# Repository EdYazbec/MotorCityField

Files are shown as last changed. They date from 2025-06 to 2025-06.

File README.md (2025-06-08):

# MotorCityField

This repository contains the source files for the Motor City Field, a full-sized FRC practice field constructed from commonly available building materials.

This field design is based on the AndyMark 2008 Wooden Field, with modifications for ease of assembly and repeated tear-down and setup.

The goal of this design is to create an adaptable, easy-to-manufacture, and reasonably close-to-life field for use by FRC teams.

The Motor City Field was designed, built, and run by the Motor City Alliance, led by FRC Team 5577, The Kinematic Wolves.

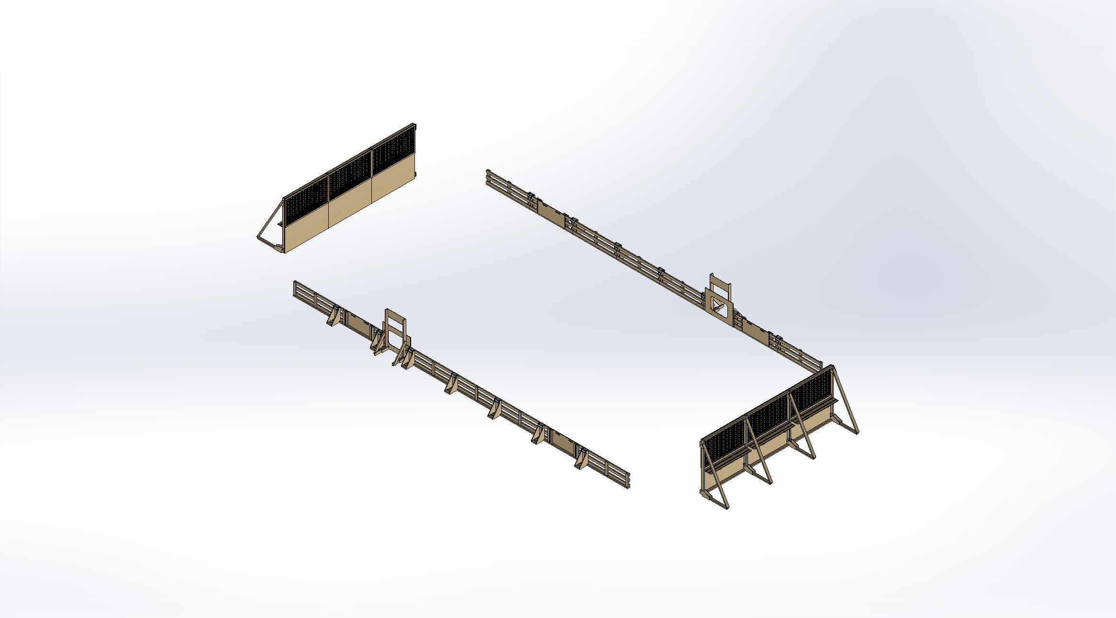
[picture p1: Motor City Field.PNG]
Motor City Field


## Limitations

Because the official FRC field changes every year, only the evergreen field elements are included in this design. These elements must be adapted with season-specific team field elements to produce a representative field for the current game.

This field is not fully enclosed by default, although it could be adapted to do so. It is intended to be combined with the season-specific team field elements to create a full, enclosed, representative field.

## Safety

FRC robots can be dangerous, especially in a testing environment. This field is designed to be robust; however, a modern FRC robot at full speed and power may exceed the safety provisions of this field.

It is the responsibility of those implementing this design to establish appropriate safety protocols to ensure the safe operation of robots on this field.

## Perimeter

The perimeter segments are designed to match the length of the standard segments used in the evergreen portion of the official field. This allows for easy reconfiguration each season and simpler integration with the season-specific team elements.

## Driver Stations

The driver station walls are designed to match the dimensions of the official field as closely as possible. These walls require additional bracing compared to the perimeter walls. Typically, the season-specific field has additional elements that connect to or insert into the driver station walls. It is up to the end user to finalize the details for each season.

## Drawing Package

The included drawing package contains engineering drawings for the evergreen portion of the Motor City Field, as well as integration with some 2025 team field elements. This package may be updated in the future.  

## Notes

- This repository focuses on the evergreen field elements; users will need to adapt or add season-specific elements each year.  
- Please refer to the LICENSE and any Third-Party Notices for licensing information.

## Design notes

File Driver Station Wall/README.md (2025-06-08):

# Driver Station Wall

The Driver Station wall is a 8' wall separating the robot drivers from the robots on the field.  
The wall is created from Driver Stations, Driver Station Braces, and any season specific field elements integrated into the wall.  
The goal is to prevent this.  
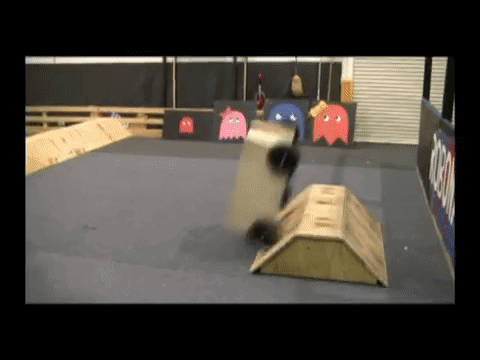
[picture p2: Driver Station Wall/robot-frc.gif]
Rouge Robot
.  

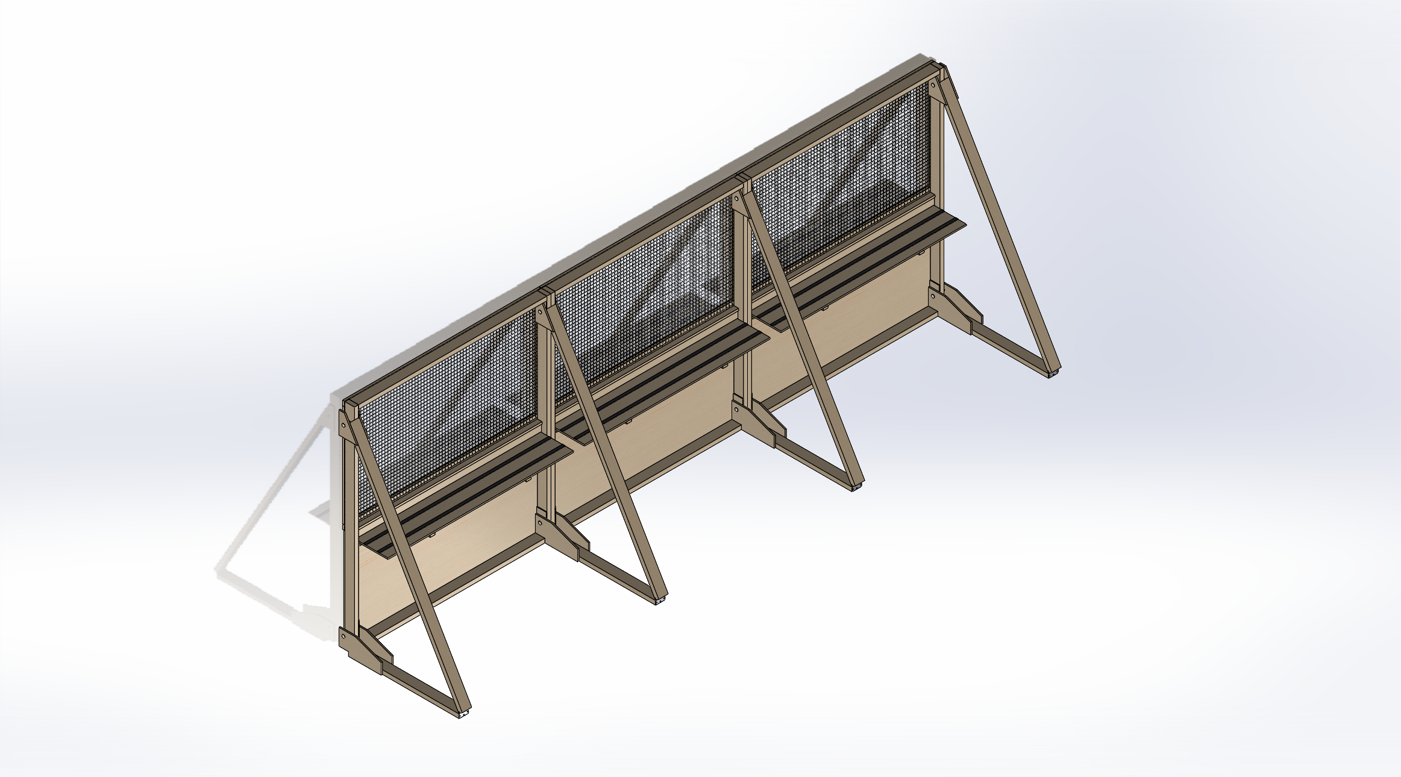
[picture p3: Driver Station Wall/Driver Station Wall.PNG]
Driver Station Wall


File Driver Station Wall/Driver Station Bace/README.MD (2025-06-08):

# Wall Brace

The Wall Brace provide structural re-enforcement between sections of the driver station wall.  
These also allow the Driver Station Walls to stand upright.  
The Wall Braces have a hing, allowing them to store easily.
It is recommended to place sand bags or similar ballast on the braces at the ground to provide additional stability.  

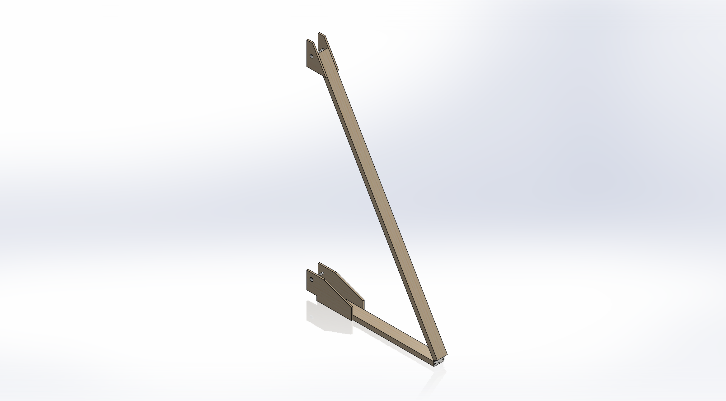
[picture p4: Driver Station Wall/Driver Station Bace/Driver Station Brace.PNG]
Driver Station Brace


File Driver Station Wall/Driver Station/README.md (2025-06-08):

# Driver Station

The Driver Station is a 8' wall segment separating the robot drivers from the robots on the field.  
The Driver Station provides a foldable shelf for the operator consol.
It is constructed from 2x4 and 1x2 lumber, as well as plywood of varying thickness.  
The steel mesh is a safety item, providing visibility for the robot operators, while protecting them from robots that may hit the wall, or from errant game pieces.  

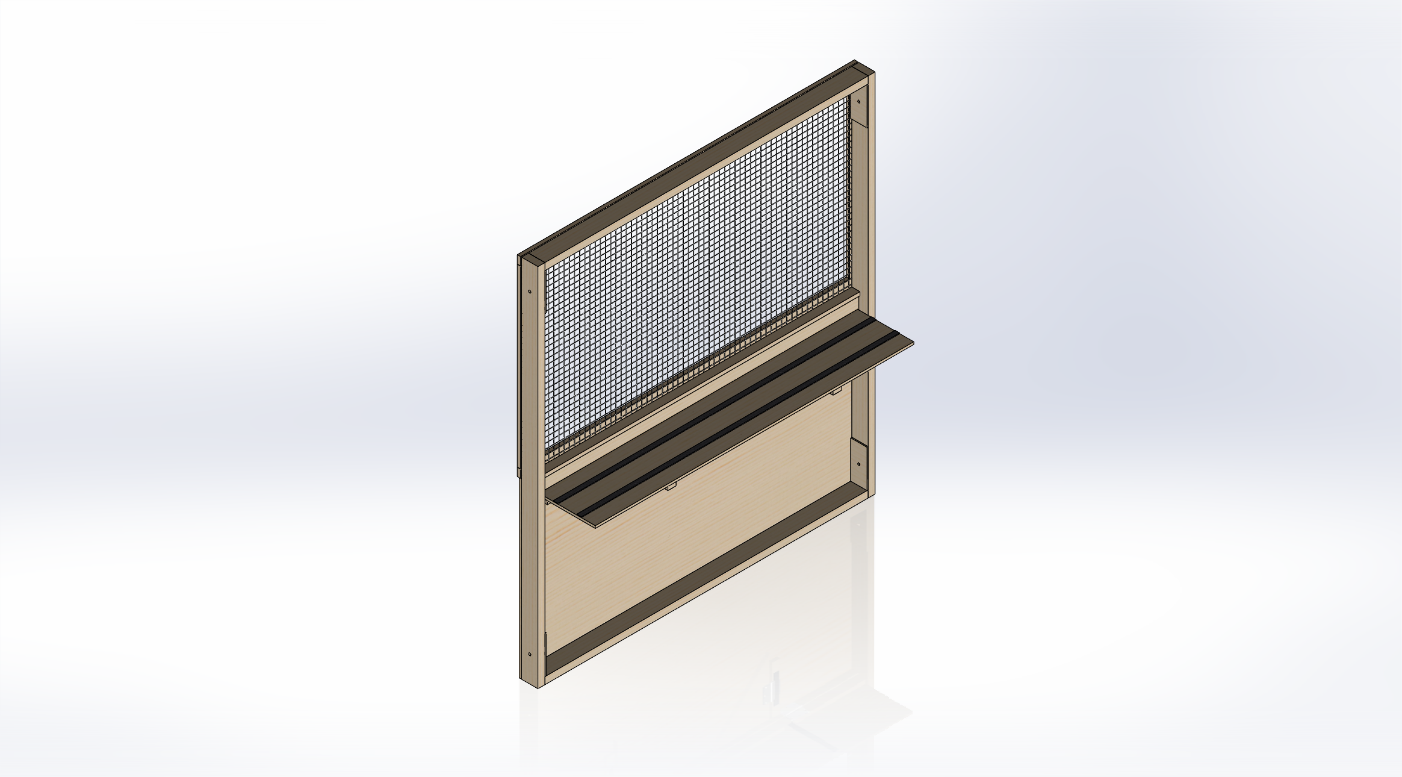
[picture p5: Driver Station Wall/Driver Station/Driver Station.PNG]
Driver Station


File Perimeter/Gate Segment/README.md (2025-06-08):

# Gate Segment

The Gate Segment is meant to provide access to the field without stepping over the perimeter wall.  
It is constructed from 2x4 and 1x2 lumber, aluminum U channel, and 3/4" plywood.  
3" screws recommended for assembly of the 2x4's.

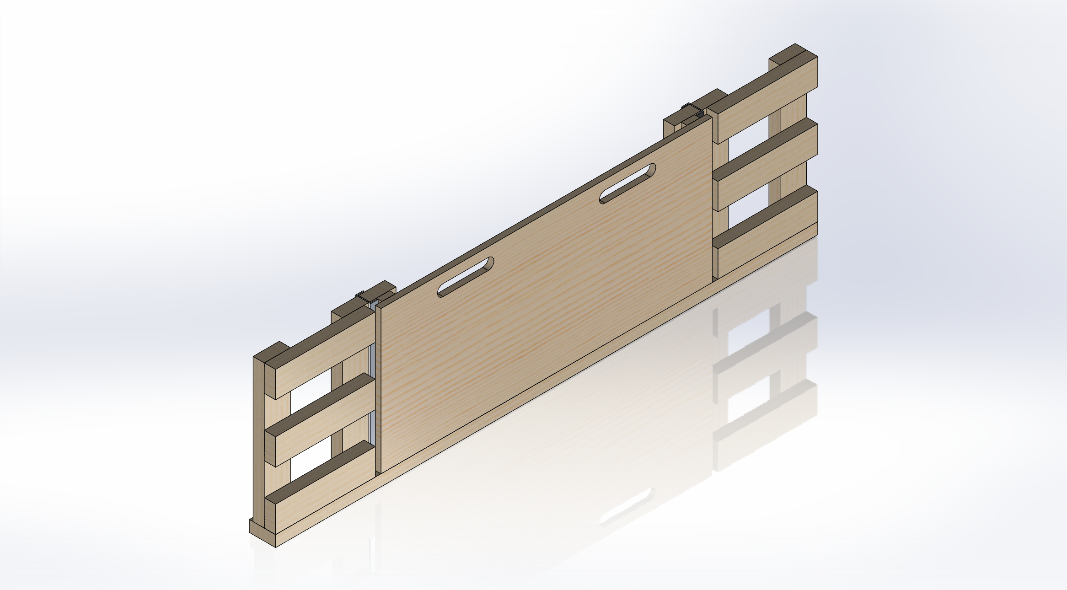
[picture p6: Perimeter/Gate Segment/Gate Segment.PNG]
Gate Segment


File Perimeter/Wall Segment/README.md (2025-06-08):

# Wall Segment

The Wall Segment forms the majority of the field perimeter wall.  
It is constructed from 4 2x4's.  
3" screws recommended for assembly of the 2x4's.  

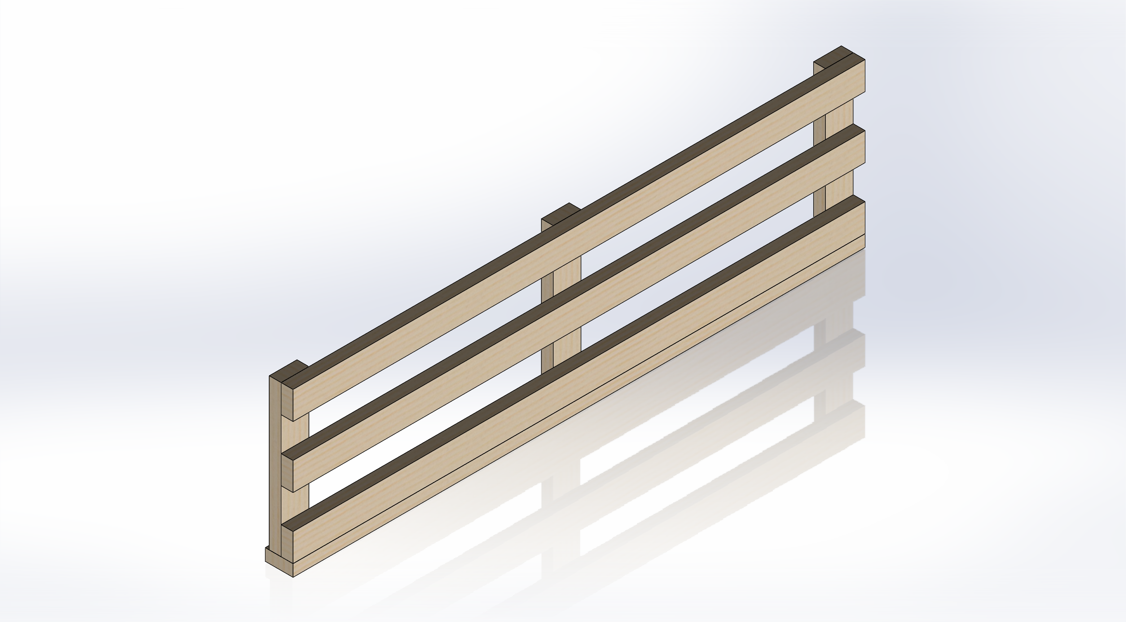
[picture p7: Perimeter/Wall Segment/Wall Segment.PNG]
Wall Segment


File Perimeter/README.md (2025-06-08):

# Perimeter

The Perimeter is a 20" tall wall that encloses the field.  
The purpose of the perimeter is to provide a clear boundary for the field, safely separating robots and humans.  
The Perimeter is constructed from Wall Segments, Gate Segments, Perimeter Braces, Field clips, and any additional season specific field elements.  

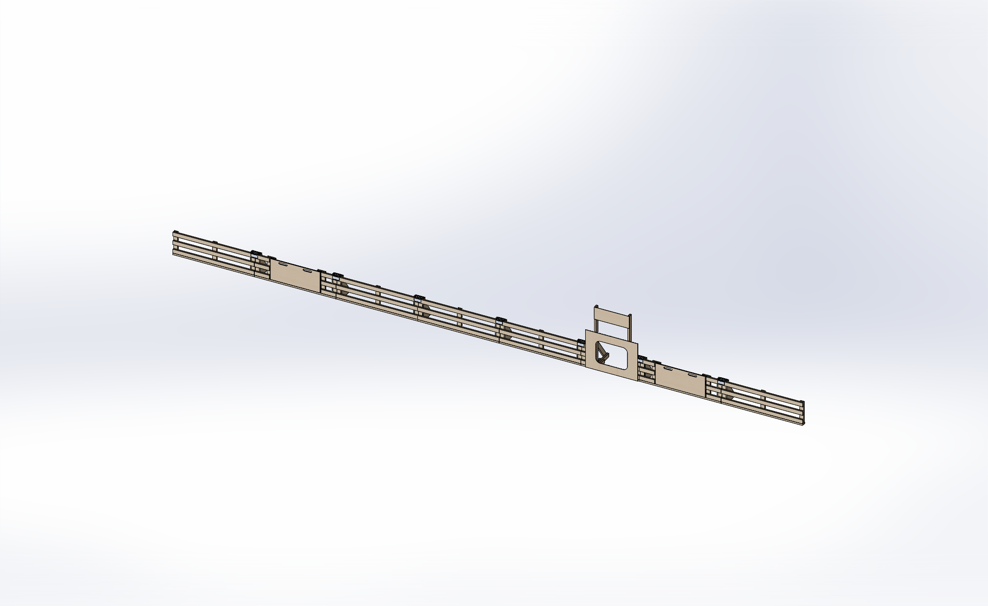
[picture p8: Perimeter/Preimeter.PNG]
Perimeter


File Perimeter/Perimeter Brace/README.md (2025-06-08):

# Perimeter Brace

The Perimeter Brace adds additional rigidity to the Perimeter wall where two Wall Segments or a Wall Segment and a Gate Segment meet.  
The Perimeter Brace is constructed from 2x4 lumber, and 3/4" plywood.  
The 2x4 lengths can be sourced from off cuts of other 2x4's from this build.  

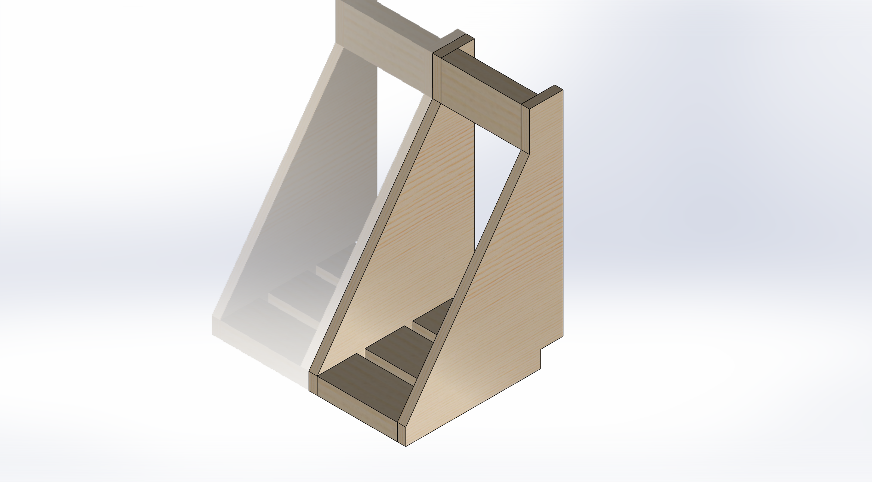
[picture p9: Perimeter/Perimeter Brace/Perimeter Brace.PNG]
Perimeter Brace


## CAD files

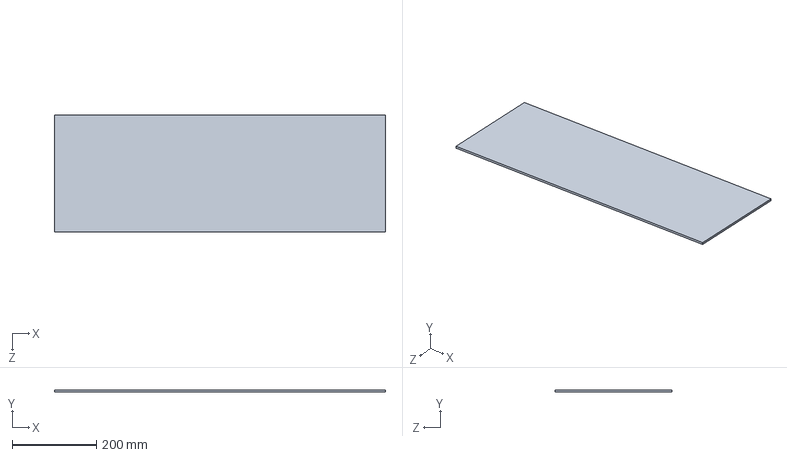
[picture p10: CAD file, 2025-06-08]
2025 Specific/TE-25100/TE-25106.SLDPRT
787.4 x 5.56 x 279.4 mm

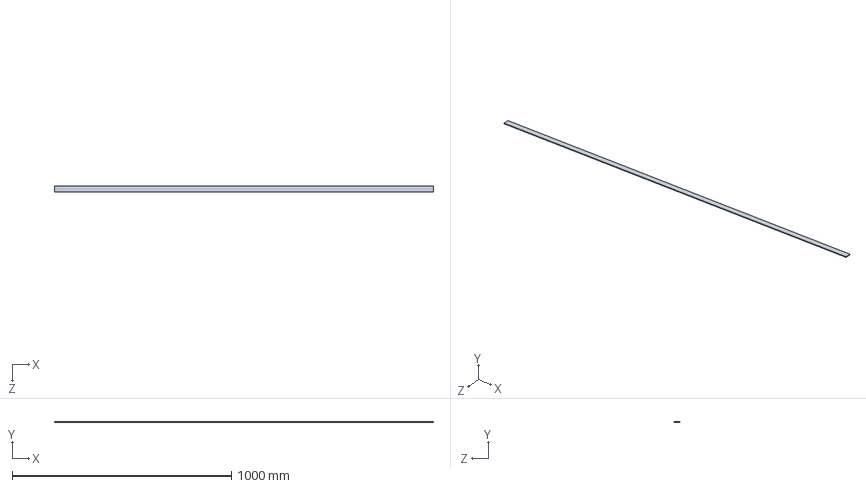
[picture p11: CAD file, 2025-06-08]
Common/1in Hook Tape.SLDPRT
1727.2 x 3.17 x 25.4 mm

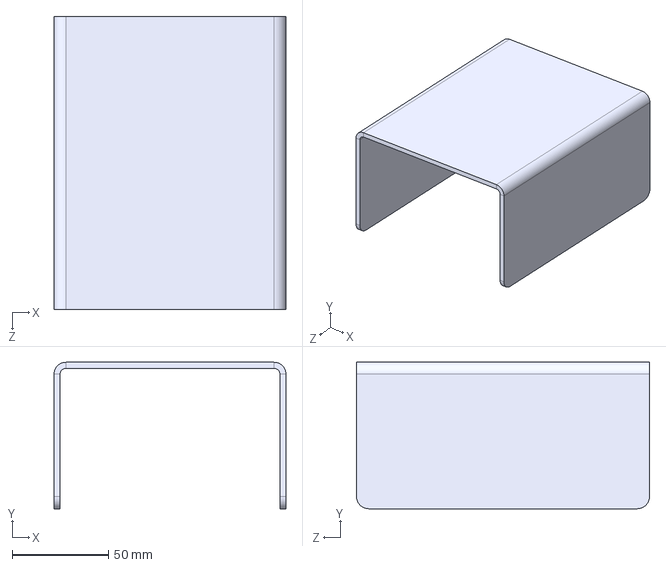
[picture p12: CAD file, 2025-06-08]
Drawing Package/Perimeter/Field Clip.STEP
120.7 x 76.2 x 152.4 mm

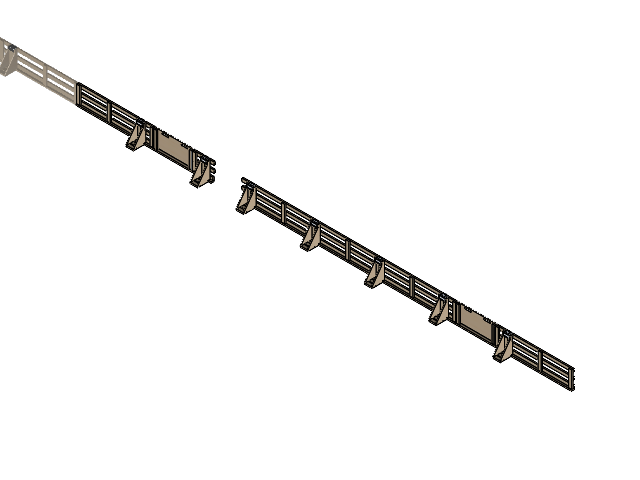
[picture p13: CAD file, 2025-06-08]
2025 Specific/Preimeter.SLDASM
2x4 x 99
Gate Door Pannel x 2
1x2 x 4
2in Hook Tape x 30
u channel x 4
TE-25101
TE-25102 x 2
TE-25103 x 2
TE-25105 x 4
TE-25106
TE-25104 x 2
Wall gusset x 14
Field Clip x 7

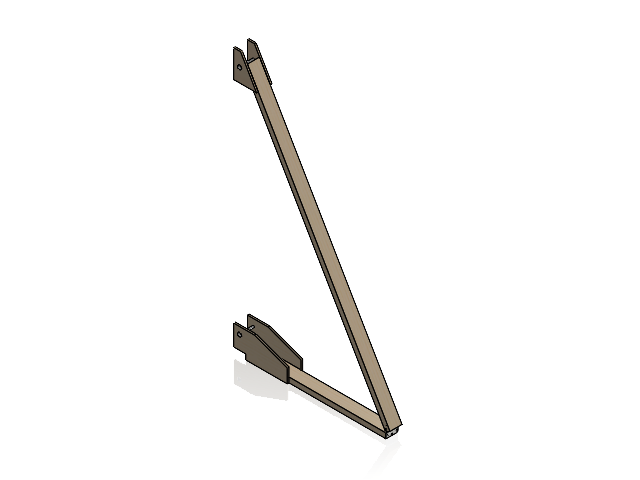
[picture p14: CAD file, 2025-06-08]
Driver Station Wall/Driver Station Bace/Driver Station Brace.SLDASM
2x4
2x4 DS angled piece
2in Hook Tape
DS Brace Bottom Fin x 2
DS Brace Top Fin x 2
92356A158 x 2
1513A51_Mortise-Mount Hinge with Holes
92141A033 x 2
92146A033 x 2
91845A310 x 2

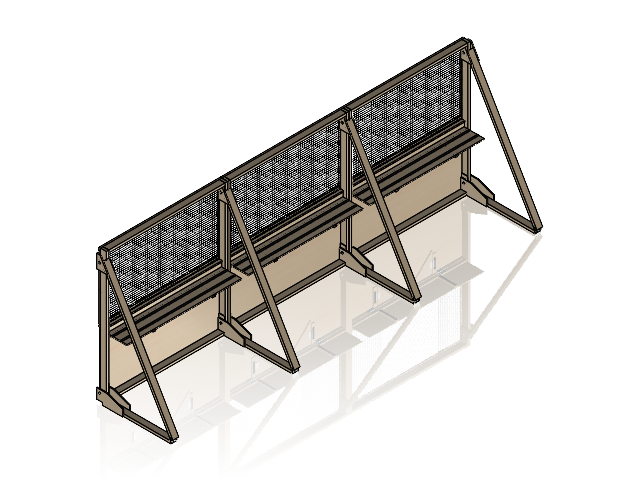
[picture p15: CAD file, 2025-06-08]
Driver Station Wall/Driver Station Wall.SLDASM
2x4 x 19
DS Wall Plate x 3
47065T295 x 3
1x2 x 30
DS Shelf Slab x 3
1513A51_Mortise-Mount Hinge with Holes x 16
1in Hook Tape x 12
DS Shelf Support x 6
0.5in Loop Tape x 6
1in Loop Tape x 6
2in Hook Tape x 7
DS Spacer x 12
2x4 DS angled piece x 4
DS Brace Bottom Fin x 8
DS Brace Top Fin x 8
92356A158 x 8
92141A033 x 8
92146A033 x 8
91845A310 x 8

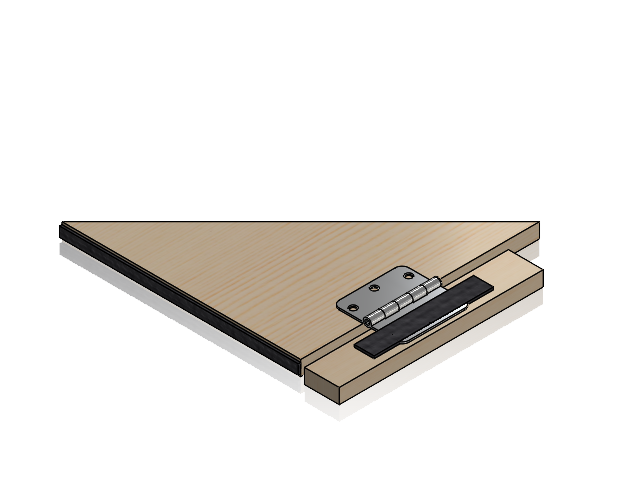
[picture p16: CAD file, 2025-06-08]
Driver Station Wall/Driver Station/DS Shelf Support LH.SLDASM
1x2
DS Shelf Support
1513A51_Mortise-Mount Hinge with Holes
0.5in Loop Tape
1in Loop Tape

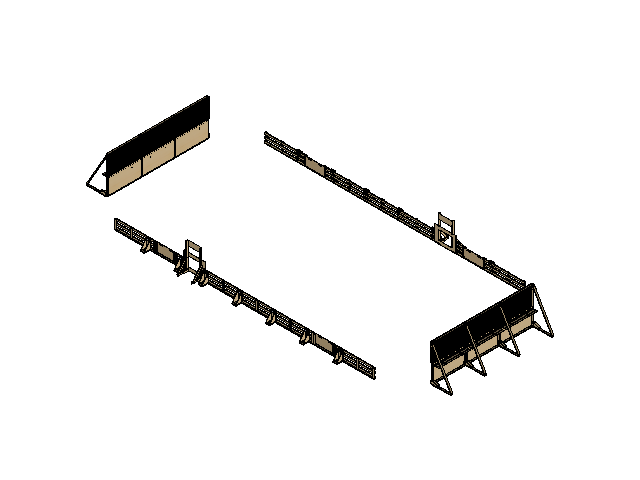
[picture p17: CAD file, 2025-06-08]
Motor City Field.SLDASM
2x4 x 236
DS Wall Plate x 6
47065T295 x 6
1x2 x 68
DS Shelf Slab x 6
1513A51_Mortise-Mount Hinge with Holes x 32
1in Hook Tape x 24
DS Shelf Support x 12
0.5in Loop Tape x 12
1in Loop Tape x 12
2in Hook Tape x 74
DS Spacer x 24
2x4 DS angled piece x 8
DS Brace Bottom Fin x 16
DS Brace Top Fin x 16
92356A158 x 16
92141A033 x 16
92146A033 x 16
91845A310 x 16
Gate Door Pannel x 4
u channel x 8
TE-25101 x 2
TE-25102 x 4
TE-25103 x 4
TE-25105 x 8
TE-25106 x 2
TE-25104 x 4
Wall gusset x 28
Field Clip x 14

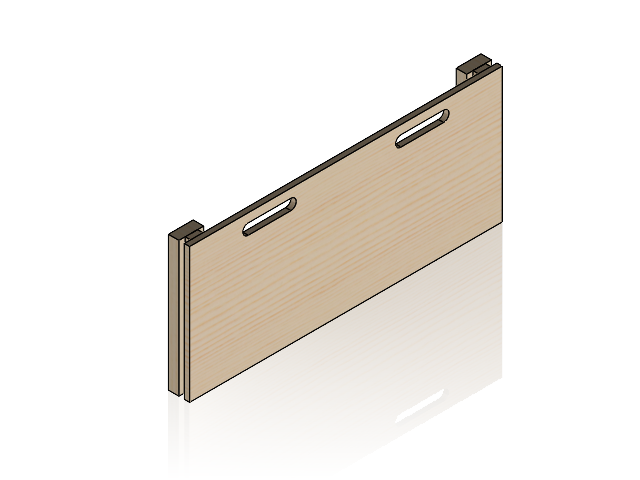
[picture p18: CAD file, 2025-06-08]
Perimeter/Gate Segment/Gate Door.SLDASM
Gate Door Pannel
2x4 x 2
1x2 x 2

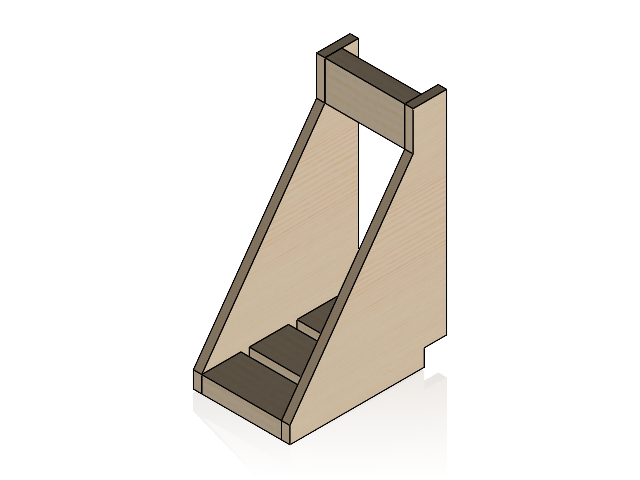
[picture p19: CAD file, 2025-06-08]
Perimeter/Perimeter Brace/Perimeter Brace.SLDASM
2x4 x 4
Wall gusset x 2
2in Hook Tape x 3

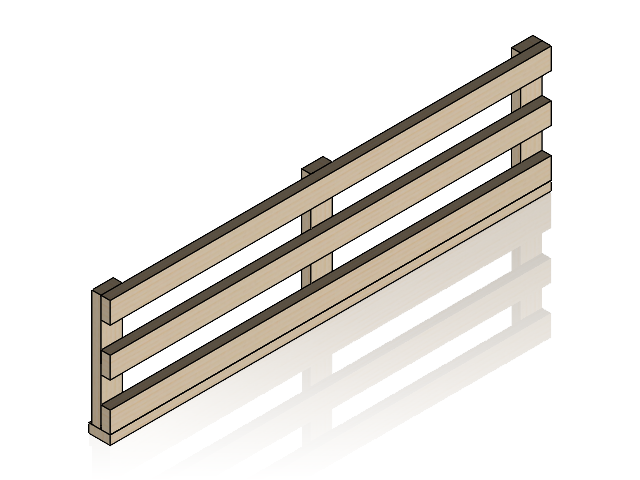
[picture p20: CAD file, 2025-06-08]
Perimeter/Wall Segment/Wall Segment.SLDASM
2x4 x 7
2in Hook Tape

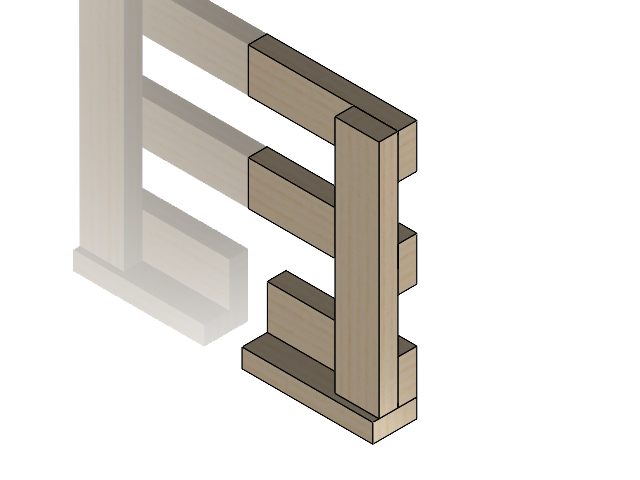
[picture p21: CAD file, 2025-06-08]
2025 Specific/Processor Padding B.SLDASM
2x4 x 5
2in Hook Tape

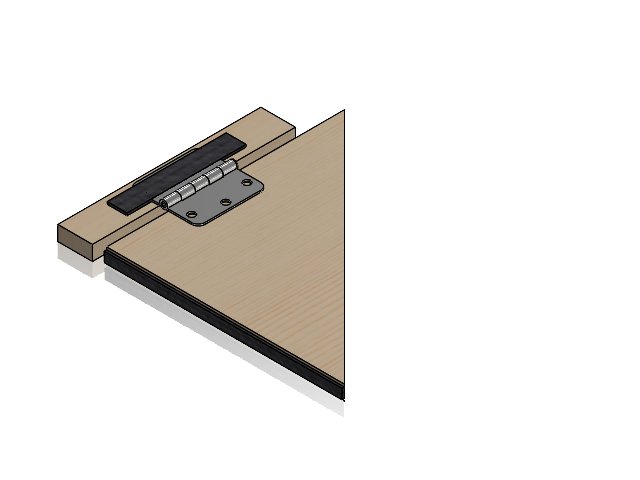
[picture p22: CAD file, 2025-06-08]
Driver Station Wall/Driver Station/DS Shelf Support RH.SLDASM
1x2
DS Shelf Support
1513A51_Mortise-Mount Hinge with Holes
0.5in Loop Tape
1in Loop Tape

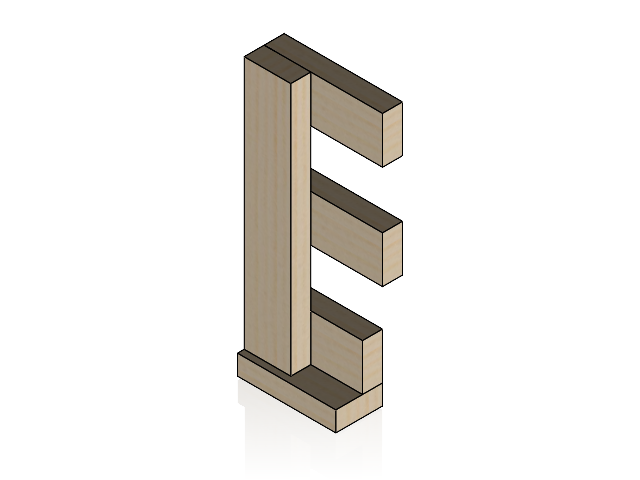
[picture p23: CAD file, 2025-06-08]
2025 Specific/Processor Padding A.SLDASM
2x4 x 5
2in Hook Tape

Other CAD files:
2025 Specific/TE-25100/TE-25100.SLDASM
Perimeter/Gate Segment/Gate Segment.SLDASM
Driver Station Wall/Driver Station/Driver Station.SLDASM
Driver Station Wall/Driver Station/DS Shelf.SLDASM
2025 Specific/Preimeter.SLDDRW
2025 Specific/Processor Padding A.SLDDRW
2025 Specific/Processor Padding B.SLDDRW
2025 Specific/TE-25100/TE-25101.SLDPRT
2025 Specific/TE-25100/TE-25102.SLDPRT
2025 Specific/TE-25100/TE-25103.SLDPRT
2025 Specific/TE-25100/TE-25104.SLDPRT
2025 Specific/TE-25100/TE-25105.SLDPRT
Common/0.5in Loop Tape.SLDPRT
Common/1in Loop Tape.SLDPRT
Common/1x2.SLDPRT
Common/2in Hook Tape.SLDPRT
Common/2x4.SLDPRT
Driver Station Wall/Driver Station Bace/2x4 DS angled piece.SLDDRW
Driver Station Wall/Driver Station Bace/2x4 DS angled piece.SLDPRT
Driver Station Wall/Driver Station Bace/DS Brace Bottom Fin.SLDDRW
Driver Station Wall/Driver Station Bace/DS Brace Bottom Fin.SLDPRT
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

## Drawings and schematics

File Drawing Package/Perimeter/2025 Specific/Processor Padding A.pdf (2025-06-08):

ITEM NO. | PART NUMBER | MATERIAL | QTY.
1 | 7.375" | 2X4 | 2

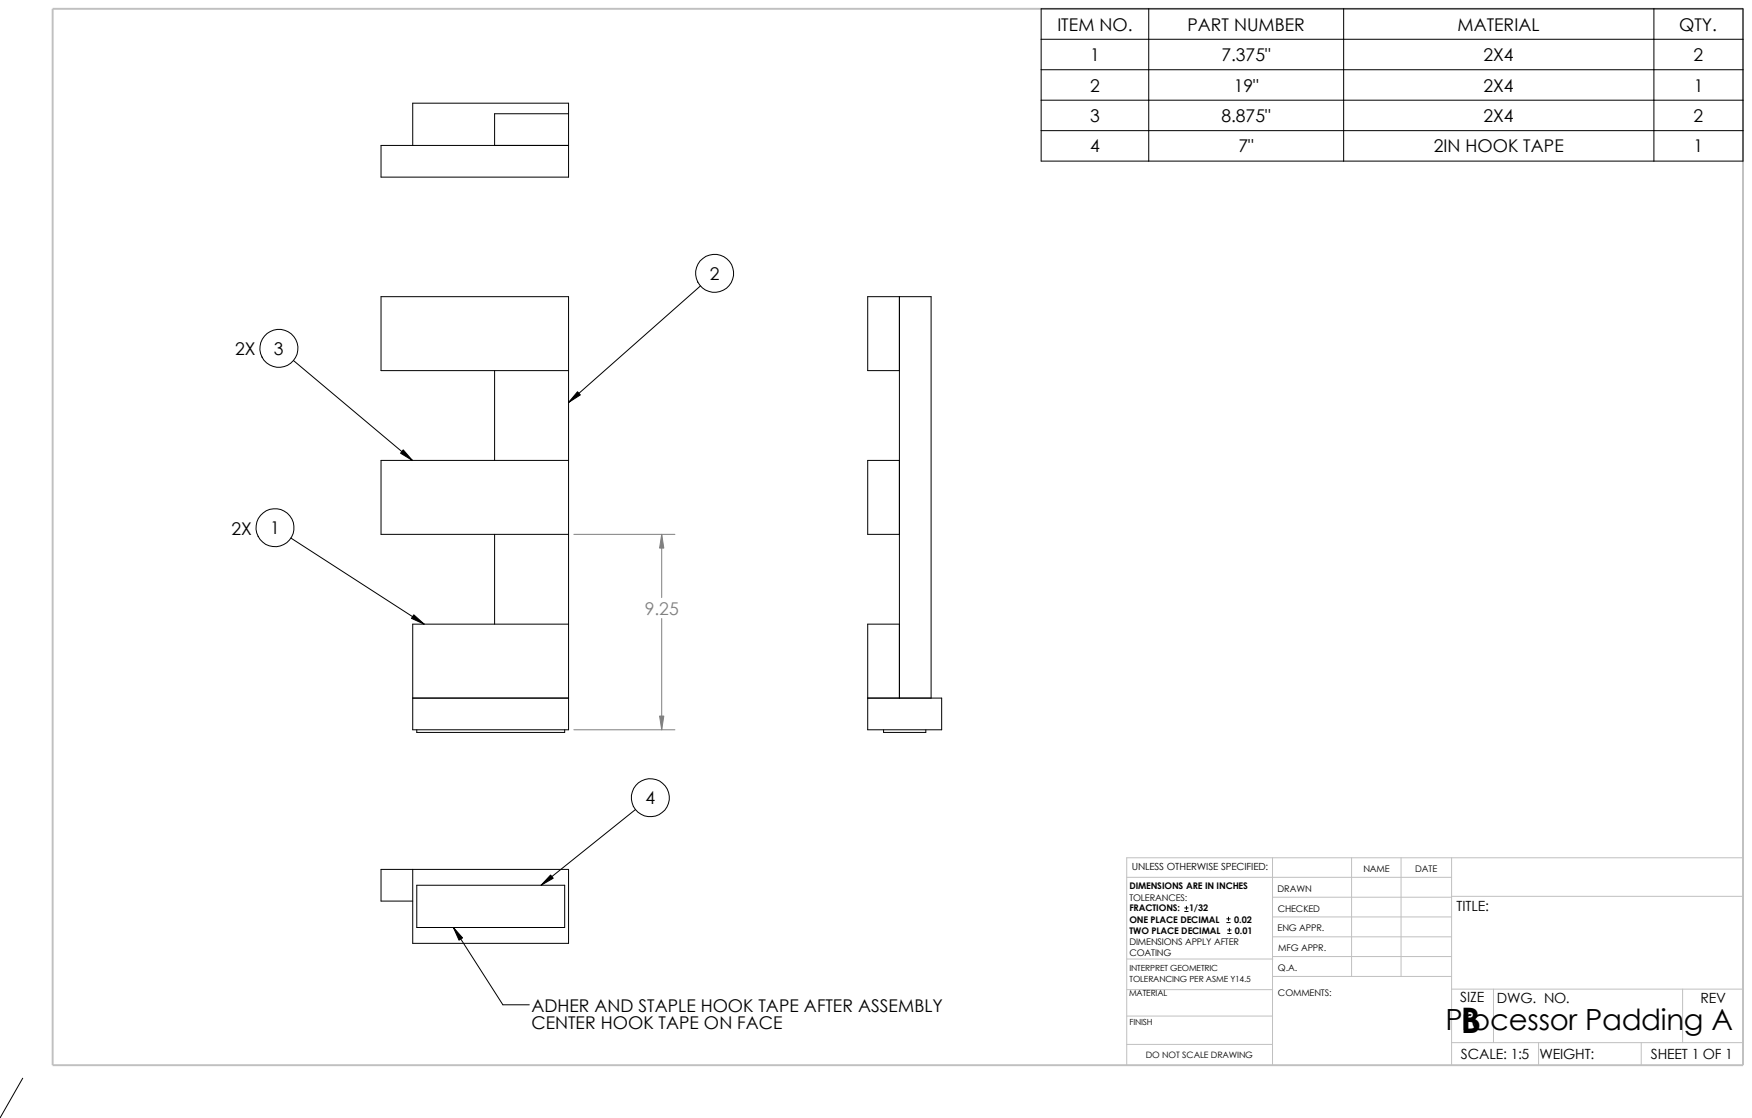
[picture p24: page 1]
SCALE: 1:5; DO NOT SCALE DRAWING; WEIGHT:; REV Processor Padding A B; SIZE; COMMENTS:; DWG. NO.; SHEET 1 OF 1; FINISH; MATERIAL

2 | 19" | 2X4 | 1
3 | 8.875" | 2X4 | 2
4 | 7" | 2IN HOOK TAPE | 1

UNLESS OTHERWISE SPECIFIED: | | NAME | DATE
DIMENSIONS ARE IN INCHES TOLERANCES: FRACTIONS: 1/32 ONE PLACE DECIMAL 0.02 TWO PLACE DECIMAL 0.01 DIMENSIONS APPLY AFTER COATING | DRAWN

CHECKED | | | TITLE:

ENG APPR.
MFG APPR.

INTERPRET GEOMETRIC TOLERANCING PER ASME Y14.5 | Q.A.

ADHER AND STAPLE HOOK TAPE AFTER ASSEMBLY
CENTER HOOK TAPE ON FACE

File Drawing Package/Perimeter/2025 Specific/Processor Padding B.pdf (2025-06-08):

3
2X

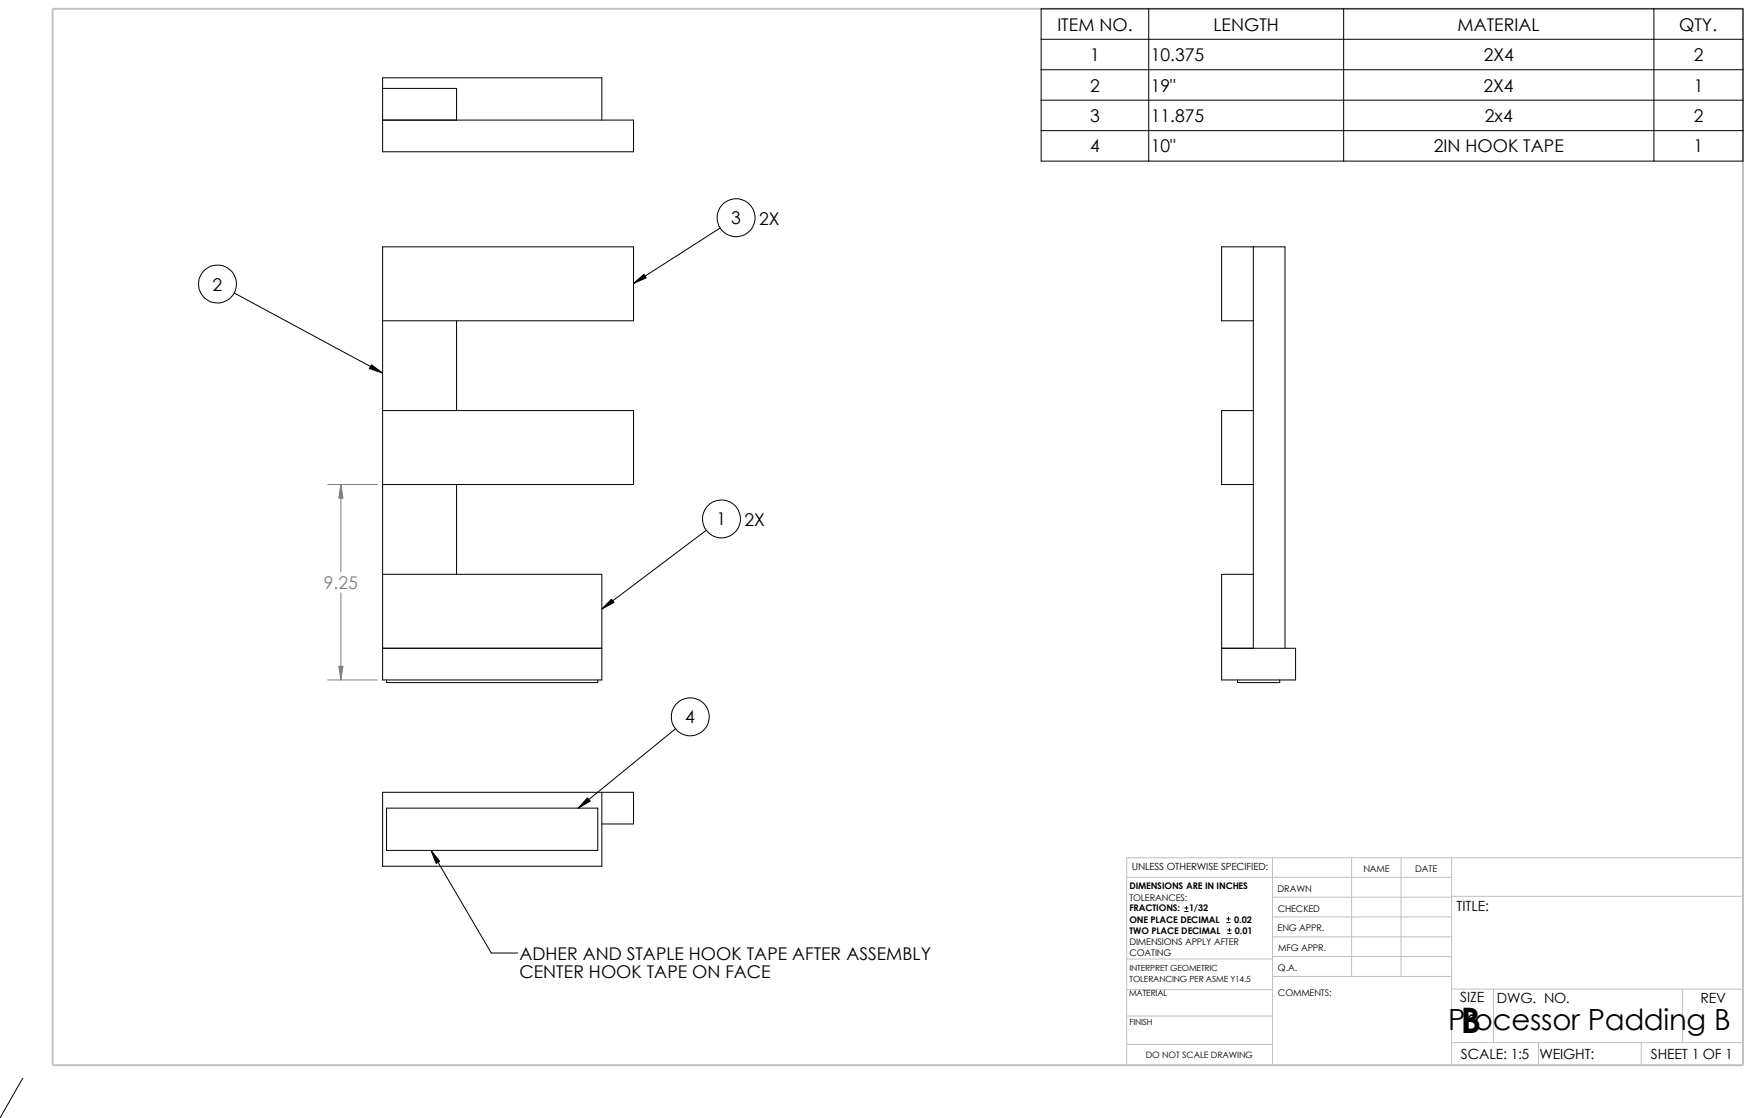
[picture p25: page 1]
SCALE: 1:5; WEIGHT:; DWG. NO.; REV; SIZE; COMMENTS:; Processor Padding B; SHEET 1 OF 1; FINISH; MATERIAL

ITEM NO. | LENGTH | MATERIAL | QTY.
1 | 10.375 | 2X4 | 2
2 | 19" | 2X4 | 1
3 | 11.875 | 2x4 | 2
4 | 10" | 2IN HOOK TAPE | 1

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

CHECKED | | | TITLE:

ENG APPR.
MFG APPR.

ADHER AND STAPLE HOOK TAPE AFTER ASSEMBLY
CENTER HOOK TAPE ON FACE

INTERPRET GEOMETRIC TOLERANCING PER ASME Y14.5 | Q.A.

DO NOT SCALE DRAWING

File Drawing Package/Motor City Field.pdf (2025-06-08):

ITEM NO. | PART NUMBER | QTY.
1 | DRIVER STATION WALL | 2

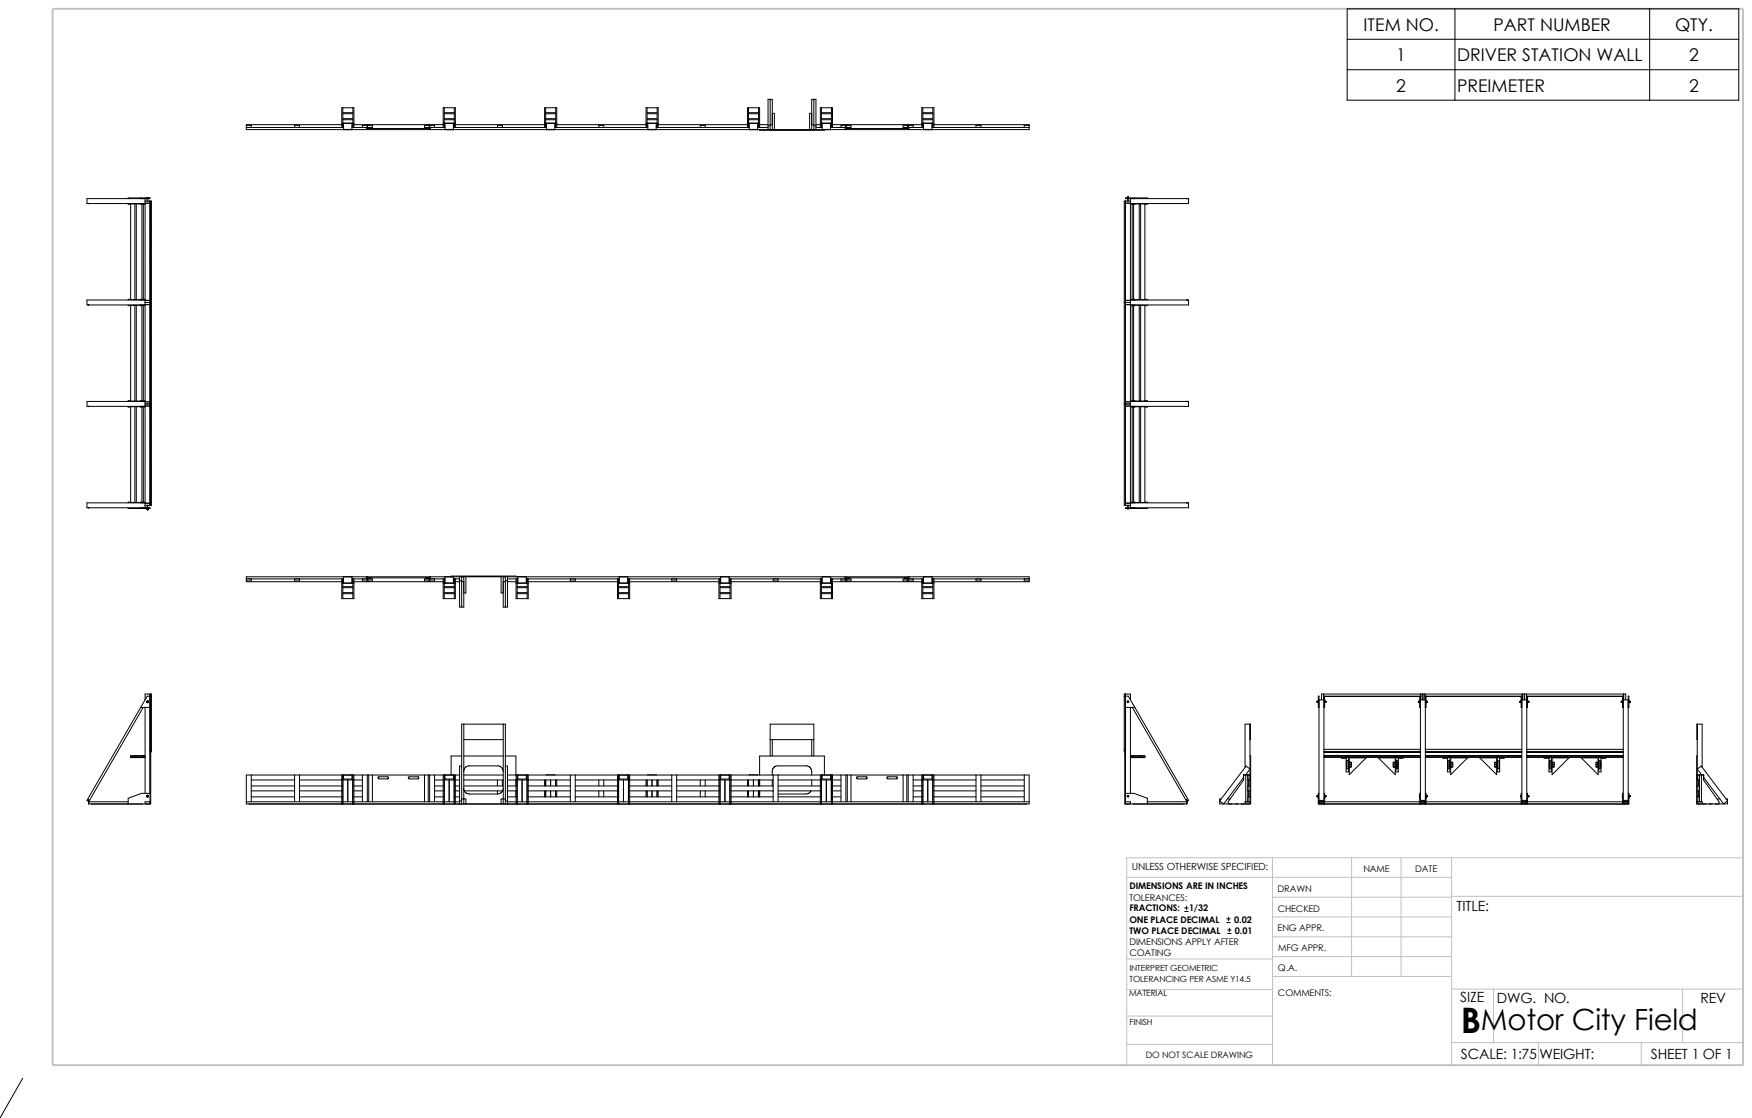
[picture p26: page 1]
COMMENTS:; DWG. NO.; REV; SCALE: 1:75 WEIGHT:; SIZE; FINISH; BMotor City Field; MATERIAL; SHEET 1 OF 1; PREIMETER

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

CHECKED | | | TITLE:

ENG APPR.
MFG APPR.

INTERPRET GEOMETRIC TOLERANCING PER ASME Y14.5 | Q.A.

DO NOT SCALE DRAWING

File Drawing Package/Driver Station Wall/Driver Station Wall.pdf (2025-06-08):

2 4X

ITEM NO. | PART NUMBER | QTY.

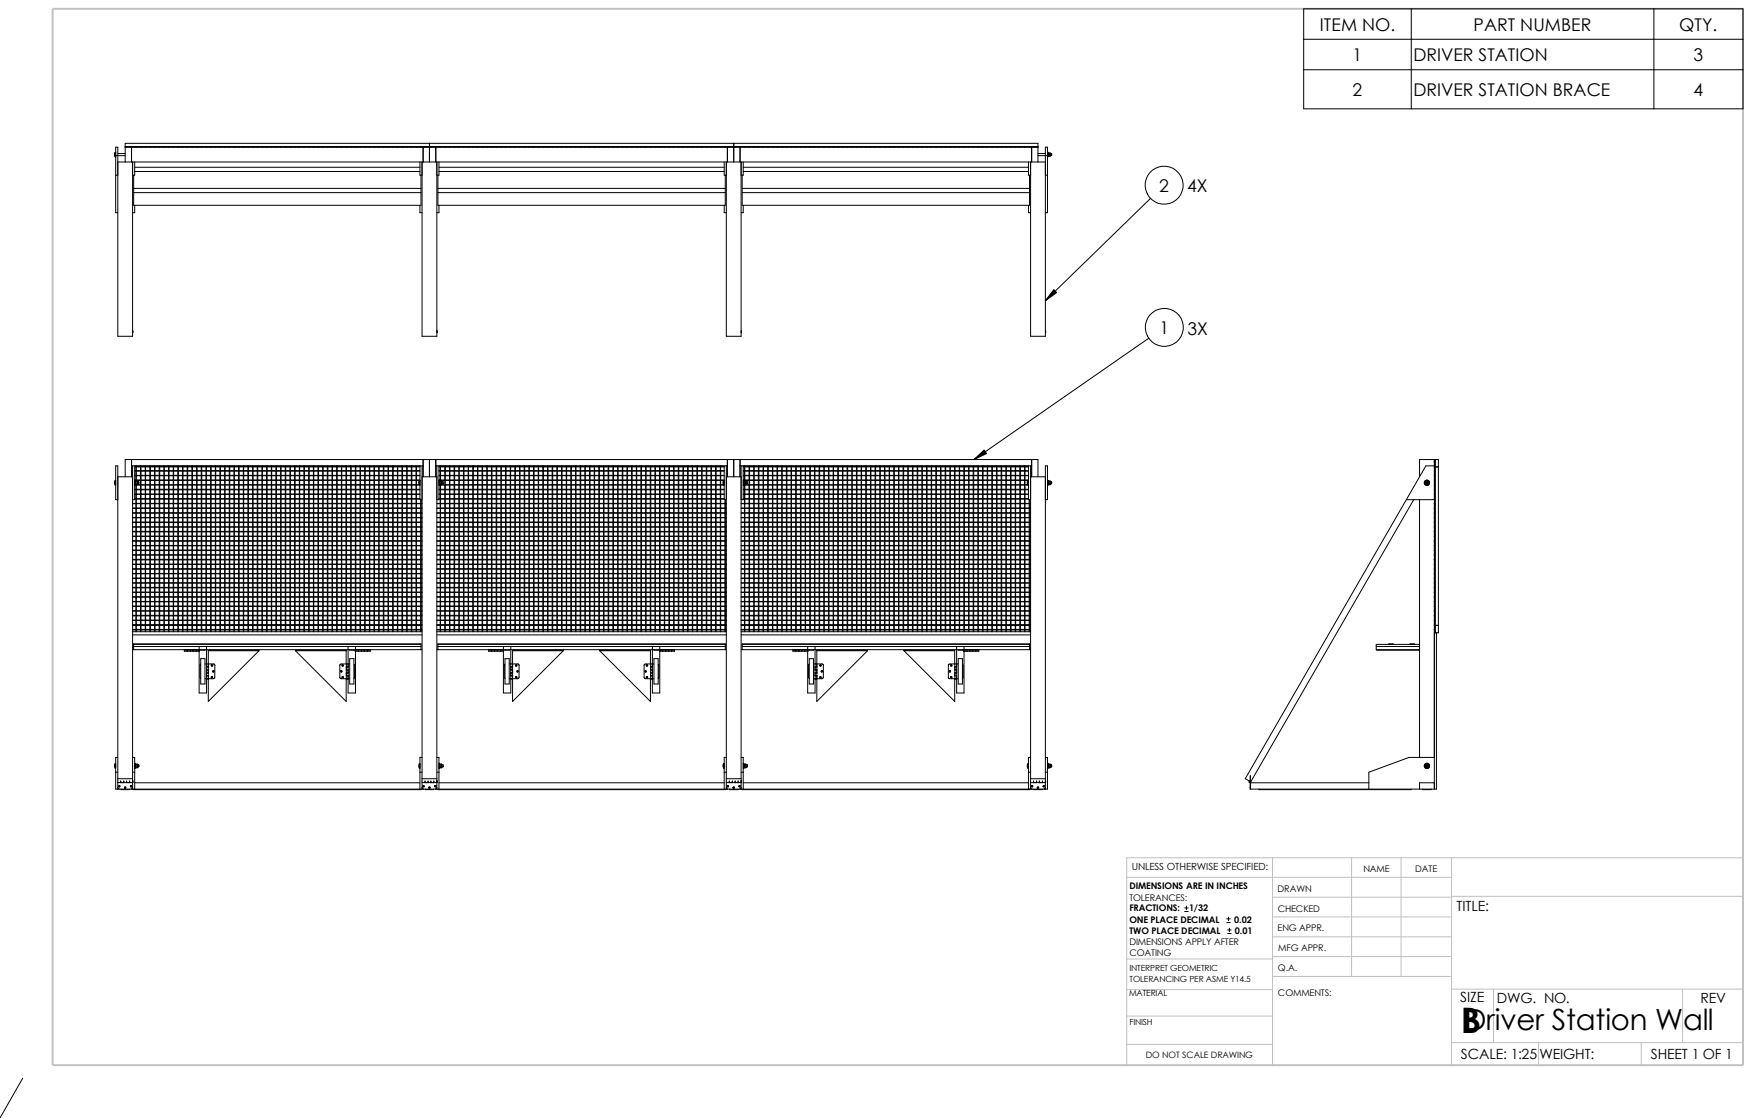
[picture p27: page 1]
SCALE: 1:25 WEIGHT:; DWG. NO.; REV; SIZE; COMMENTS:; Driver Station Wall; SHEET 1 OF 1; FINISH; MATERIAL; DRIVER STATION; DRIVER STATION BRACE

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

CHECKED | | | TITLE:

ENG APPR.
MFG APPR.

INTERPRET GEOMETRIC TOLERANCING PER ASME Y14.5 | Q.A.

DO NOT SCALE DRAWING

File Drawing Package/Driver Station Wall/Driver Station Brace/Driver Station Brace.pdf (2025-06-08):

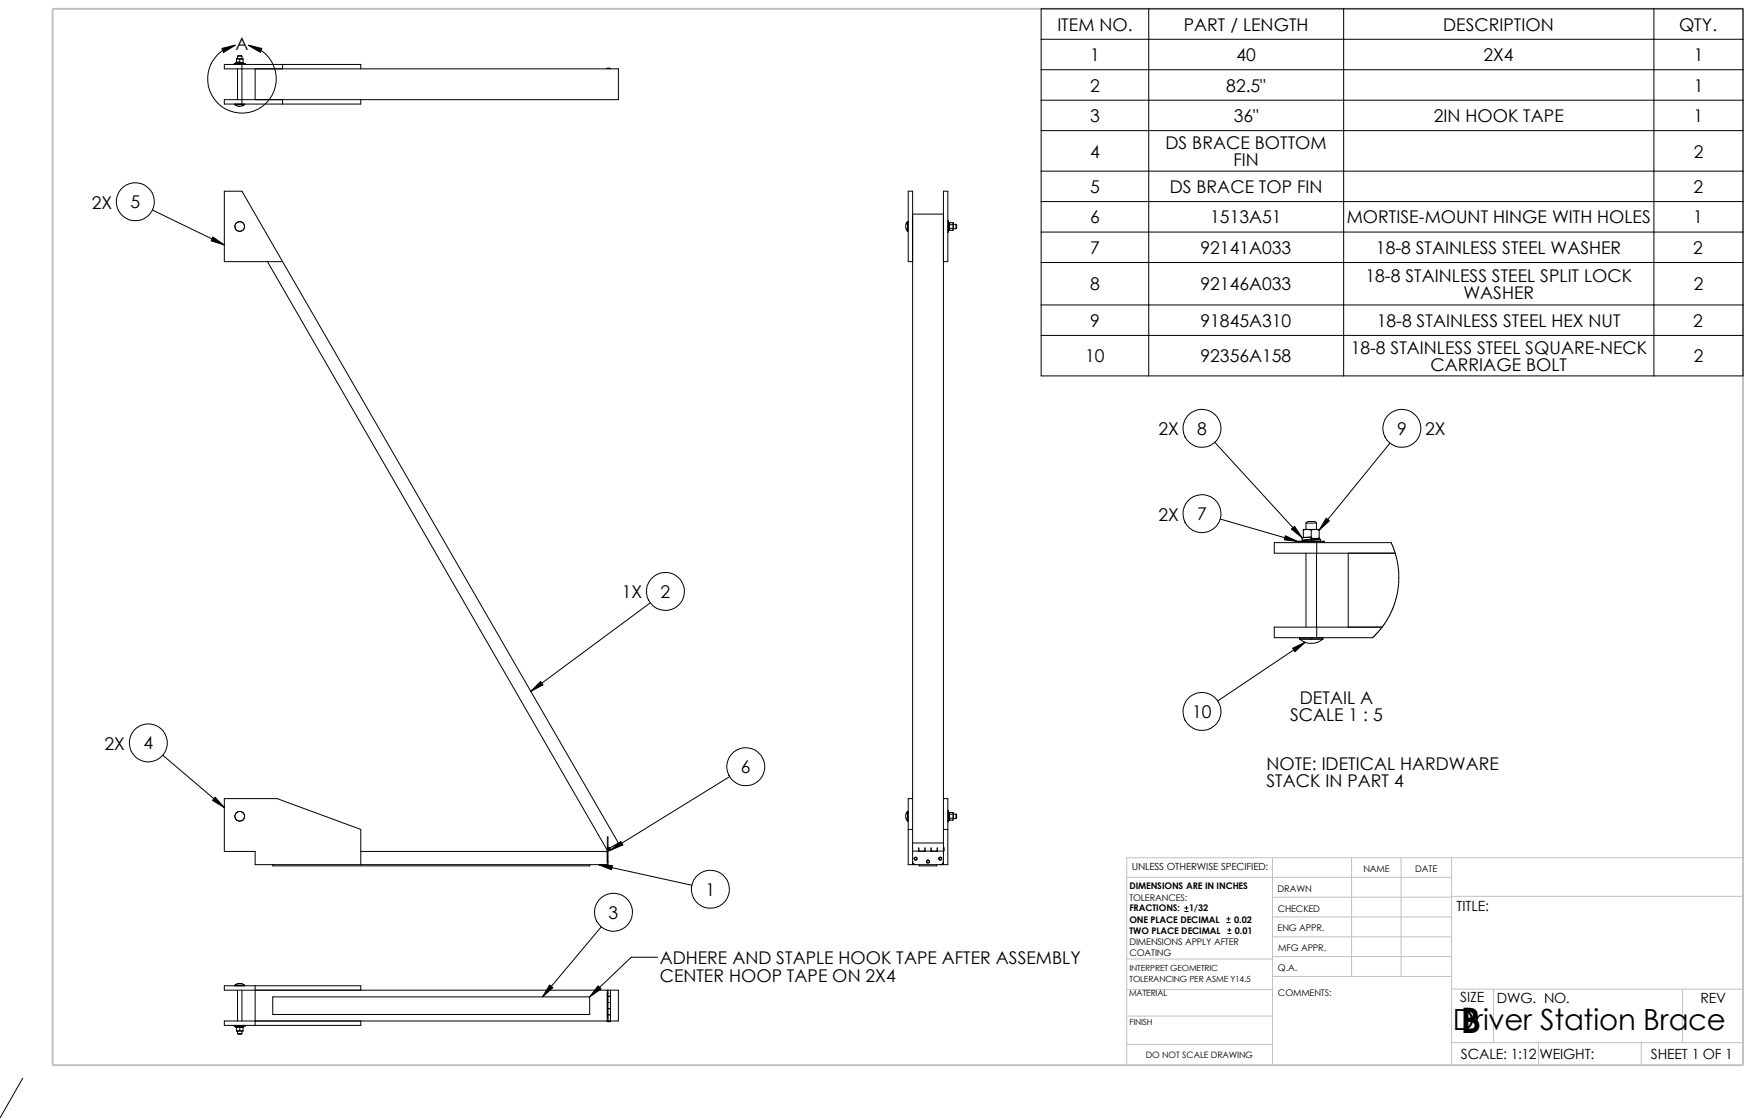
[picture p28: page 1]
COMMENTS:; DWG. NO.; REV; SCALE: 1:12 WEIGHT:; SIZE; FINISH; Driver Station Brace B; MATERIAL; SHEET 1 OF 1; DETAIL A SCALE 1 : 5

A | ITEM NO. | PART / LENGTH | DESCRIPTION | QTY.

1 | 40 | 2X4 | 1
2 | 82.5" | | 1
3 | 36" | 2IN HOOK TAPE | 1
4 DS BRACE BOTTOM | FIN | | 2

5 | DS BRACE TOP FIN | | 2
6 | 1513A51 | MORTISE-MOUNT HINGE WITH HOLES | 1
7 | 92141A033 | 18-8 STAINLESS STEEL WASHER | 2
8 | 92146A033 | 18-8 STAINLESS STEEL SPLIT LOCK WASHER | 2

9 | 91845A310 | 18-8 STAINLESS STEEL HEX NUT | 2
10 | 92356A158 | 18-8 STAINLESS STEEL SQUARE-NECK CARRIAGE BOLT | 2

NOTE: IDETICAL HARDWARE
STACK IN PART 4

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

CHECKED | | | TITLE:

ENG APPR.
MFG APPR.

ADHERE AND STAPLE HOOK TAPE AFTER ASSEMBLY
CENTER HOOP TAPE ON 2X4

INTERPRET GEOMETRIC TOLERANCING PER ASME Y14.5 | Q.A.

DO NOT SCALE DRAWING

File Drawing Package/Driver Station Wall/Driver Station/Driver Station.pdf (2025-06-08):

2X 5

4

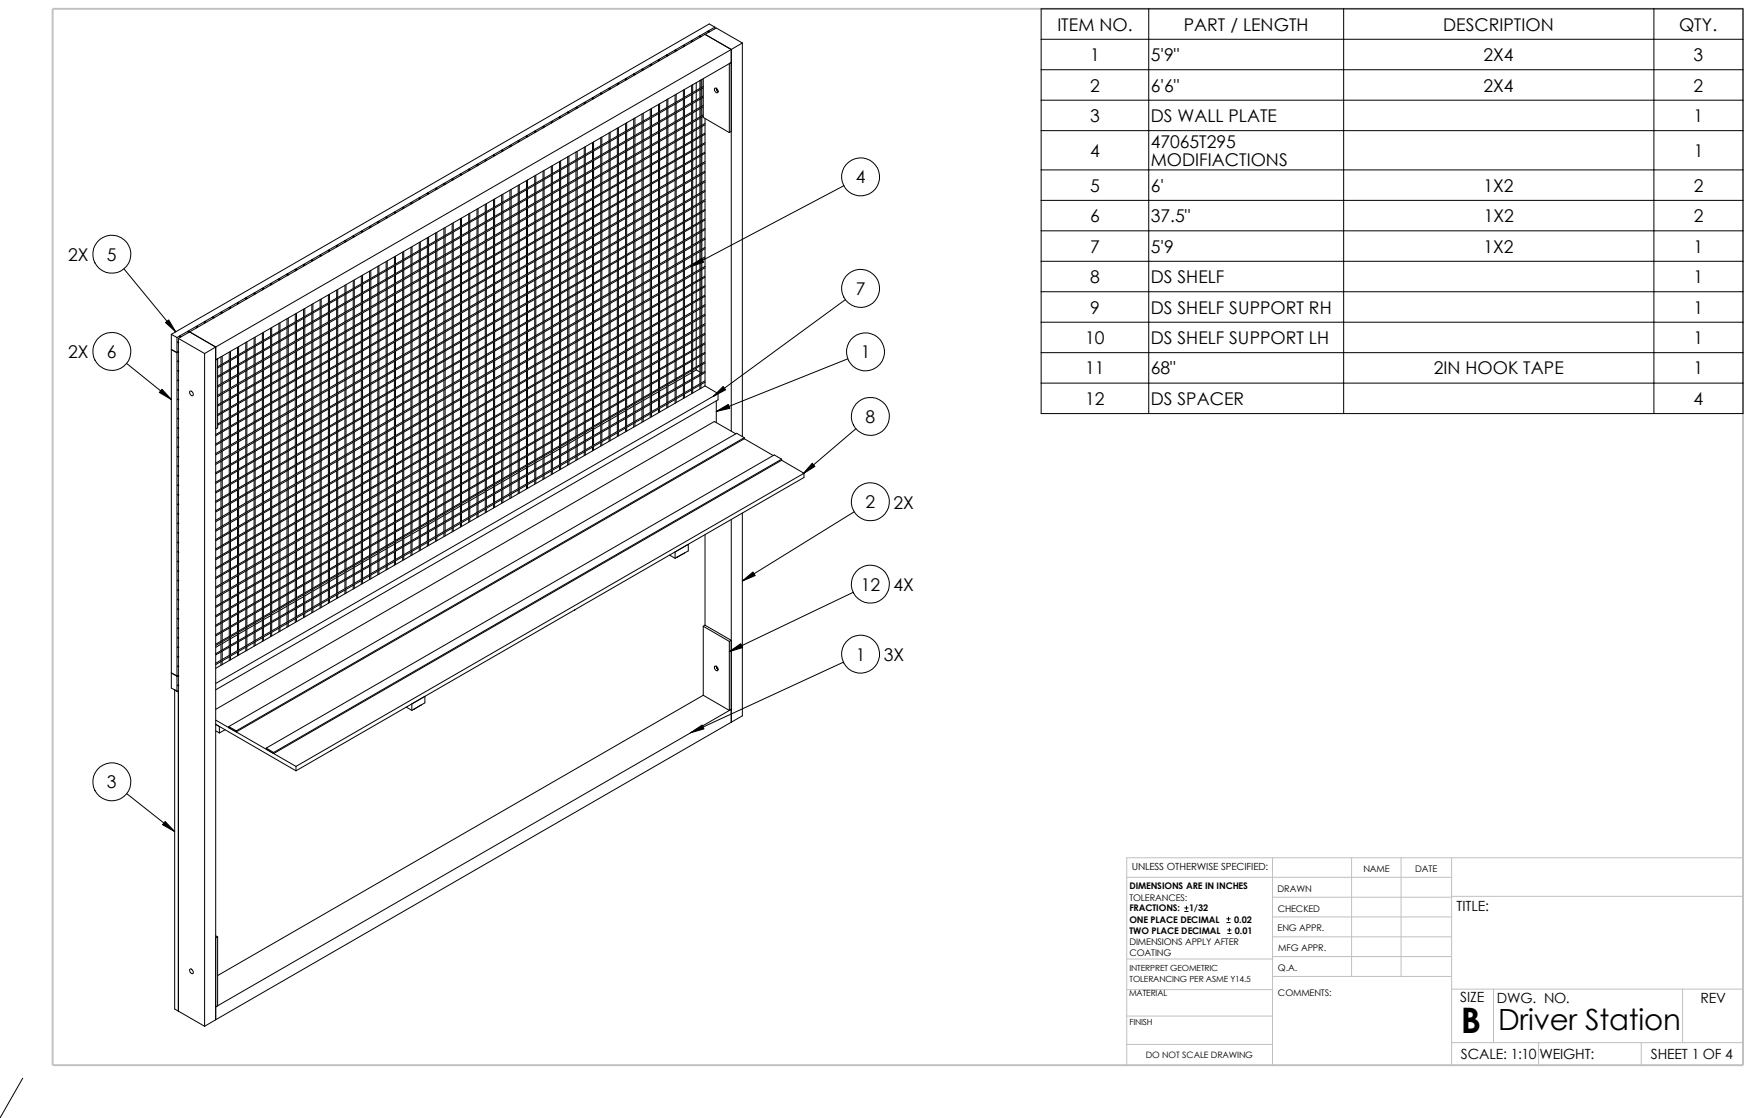
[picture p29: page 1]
SCALE: 1:10 WEIGHT:; DWG. NO.; REV; SIZE; COMMENTS:; Driver Station; SHEET 1 OF 4; FINISH; MATERIAL

ITEM NO. | PART / LENGTH | DESCRIPTION | QTY.
1 | 5'9" | 2X4 | 3
2 | 6'6" | 2X4 | 2
3 | DS WALL PLATE | | 1
4 | 47065T295 MODIFIACTIONS | | 1

5 | 6' | 1X2 | 2
6 | 37.5" | 1X2 | 2
7 | 5'9 | 1X2 | 1
8 | DS SHELF | | 1
9 | DS SHELF SUPPORT RH | | 1
10 | DS SHELF SUPPORT LH | | 1
11 | 68" | 2IN HOOK TAPE | 1
12 | DS SPACER | | 4

UNLESS OTHERWISE SPECIFIED: | | NAME | DATE
DIMENSIONS ARE IN INCHES TOLERANCES: FRACTIONS: 1/32 ONE PLACE DECIMAL 0.02 TWO PLACE DECIMAL 0.01 DIMENSIONS APPLY AFTER COATING | DRAWN

CHECKED | | | TITLE:

ENG APPR.
MFG APPR.

INTERPRET GEOMETRIC TOLERANCING PER ASME Y14.5 | Q.A.

DO NOT SCALE DRAWING

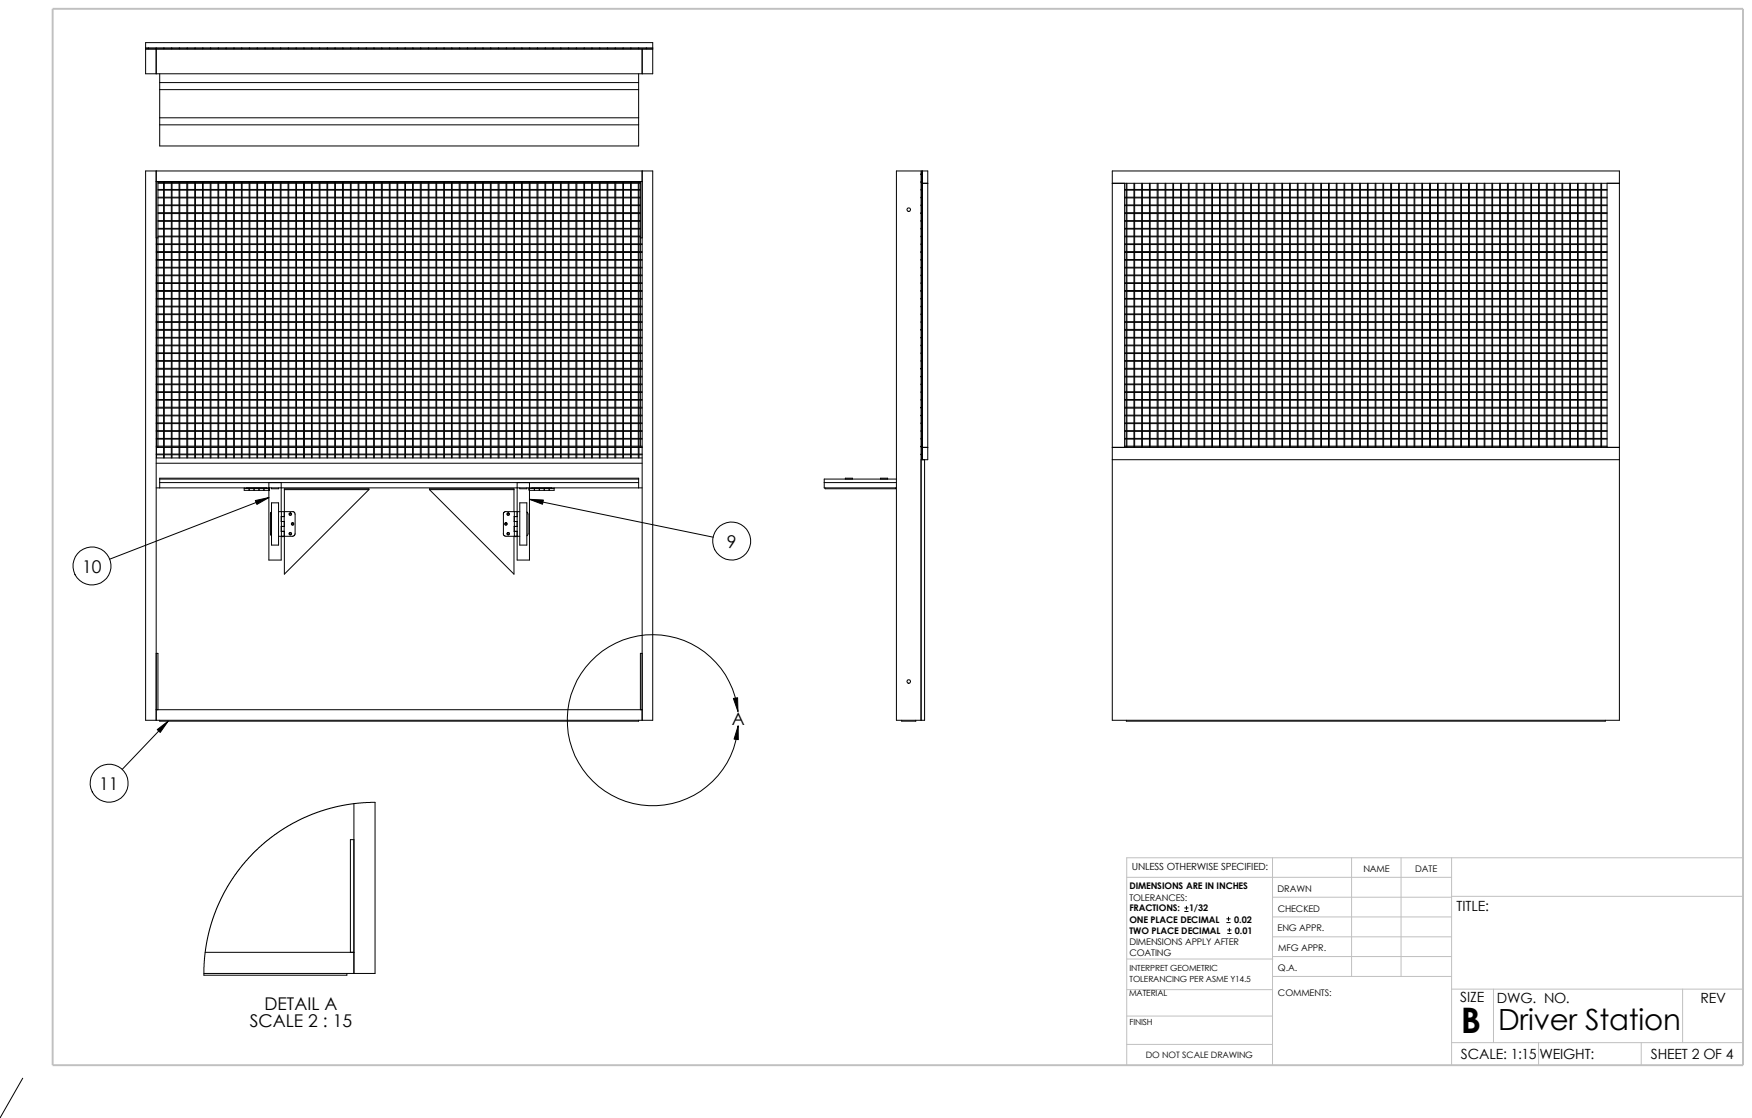
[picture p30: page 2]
Driver Station; SHEET 2 OF 4; SCALE: 1:15 WEIGHT:; DWG. NO.; REV; SIZE; COMMENTS:; MATERIAL; DETAIL A SCALE 2 : 15

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

CHECKED | | | TITLE:

ENG APPR.
MFG APPR.

INTERPRET GEOMETRIC TOLERANCING PER ASME Y14.5 | Q.A.

4X 1

# " THRU ALL

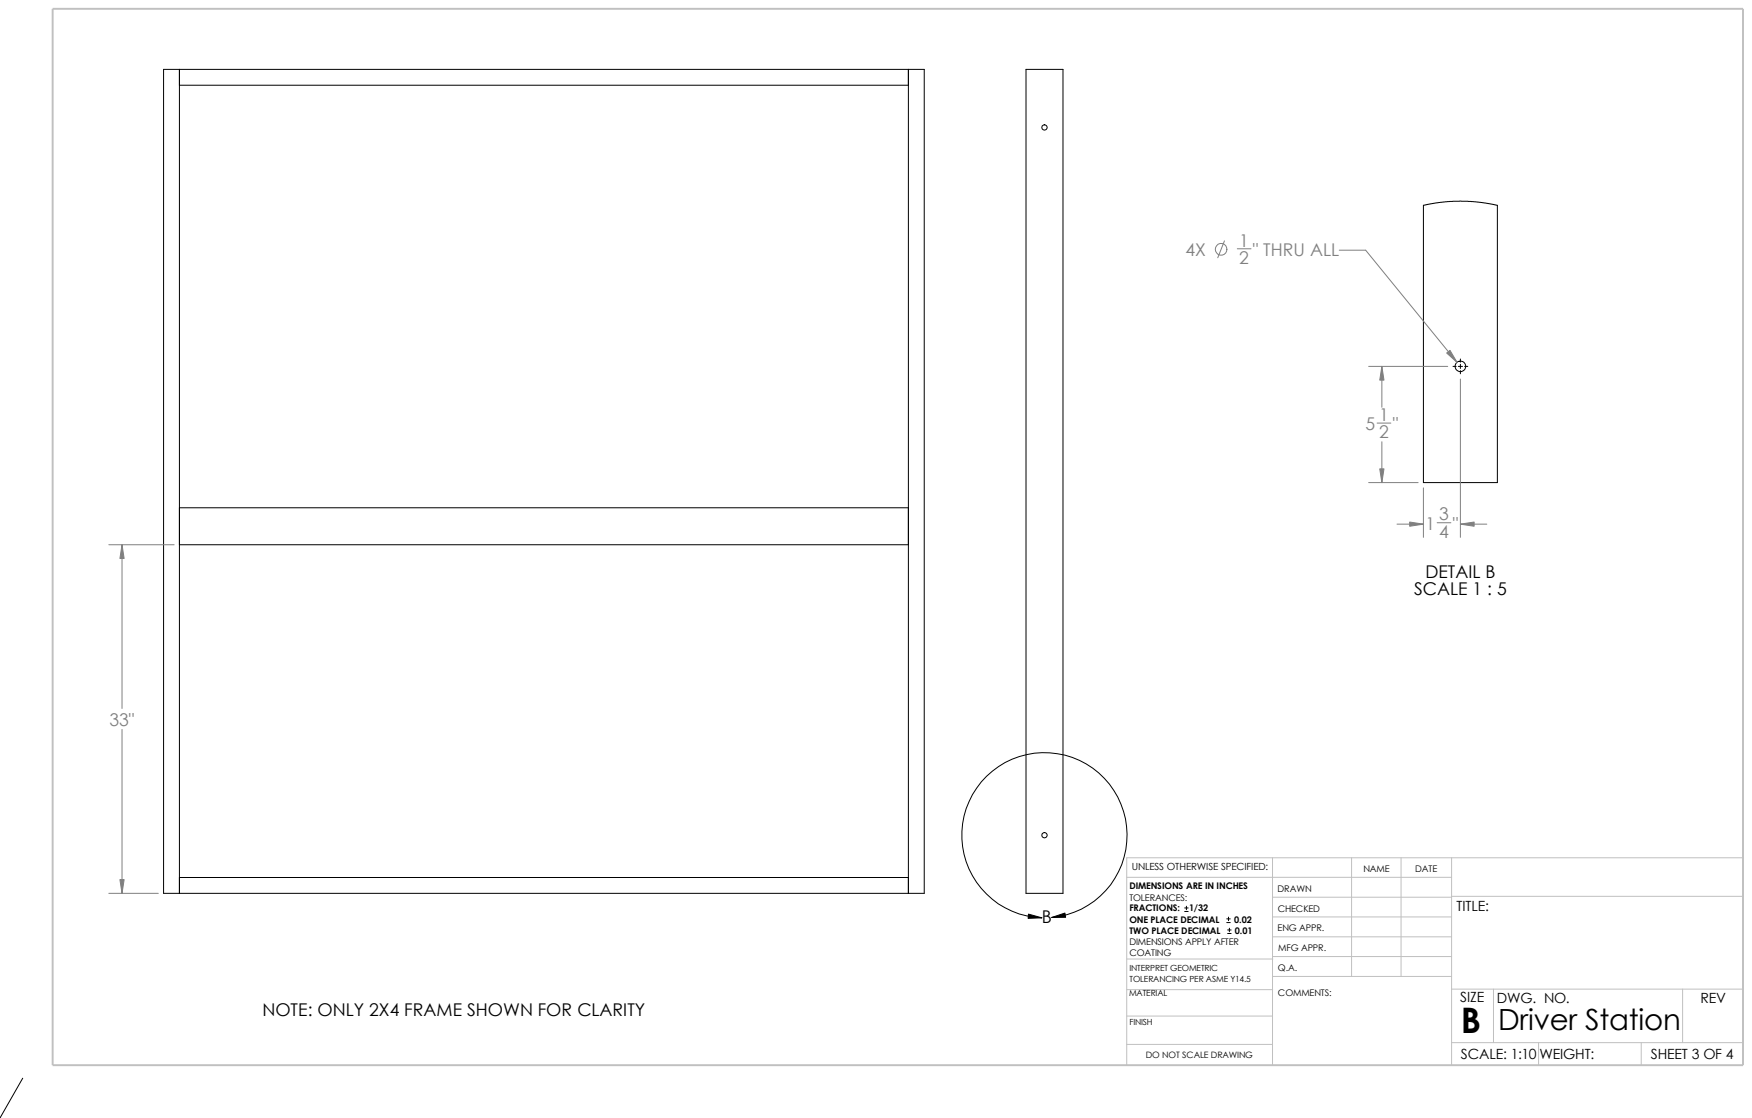
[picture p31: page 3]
Driver Station; SHEET 3 OF 4; DWG. NO.; REV; SIZE; TITLE:; COMMENTS:; CHECKED; MATERIAL; DETAIL B SCALE 1 : 5

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

ENG APPR.
MFG APPR.

INTERPRET GEOMETRIC TOLERANCING PER ASME Y14.5 | Q.A.

NOTE: ONLY 2X4 FRAME SHOWN FOR CLARITY

C
5

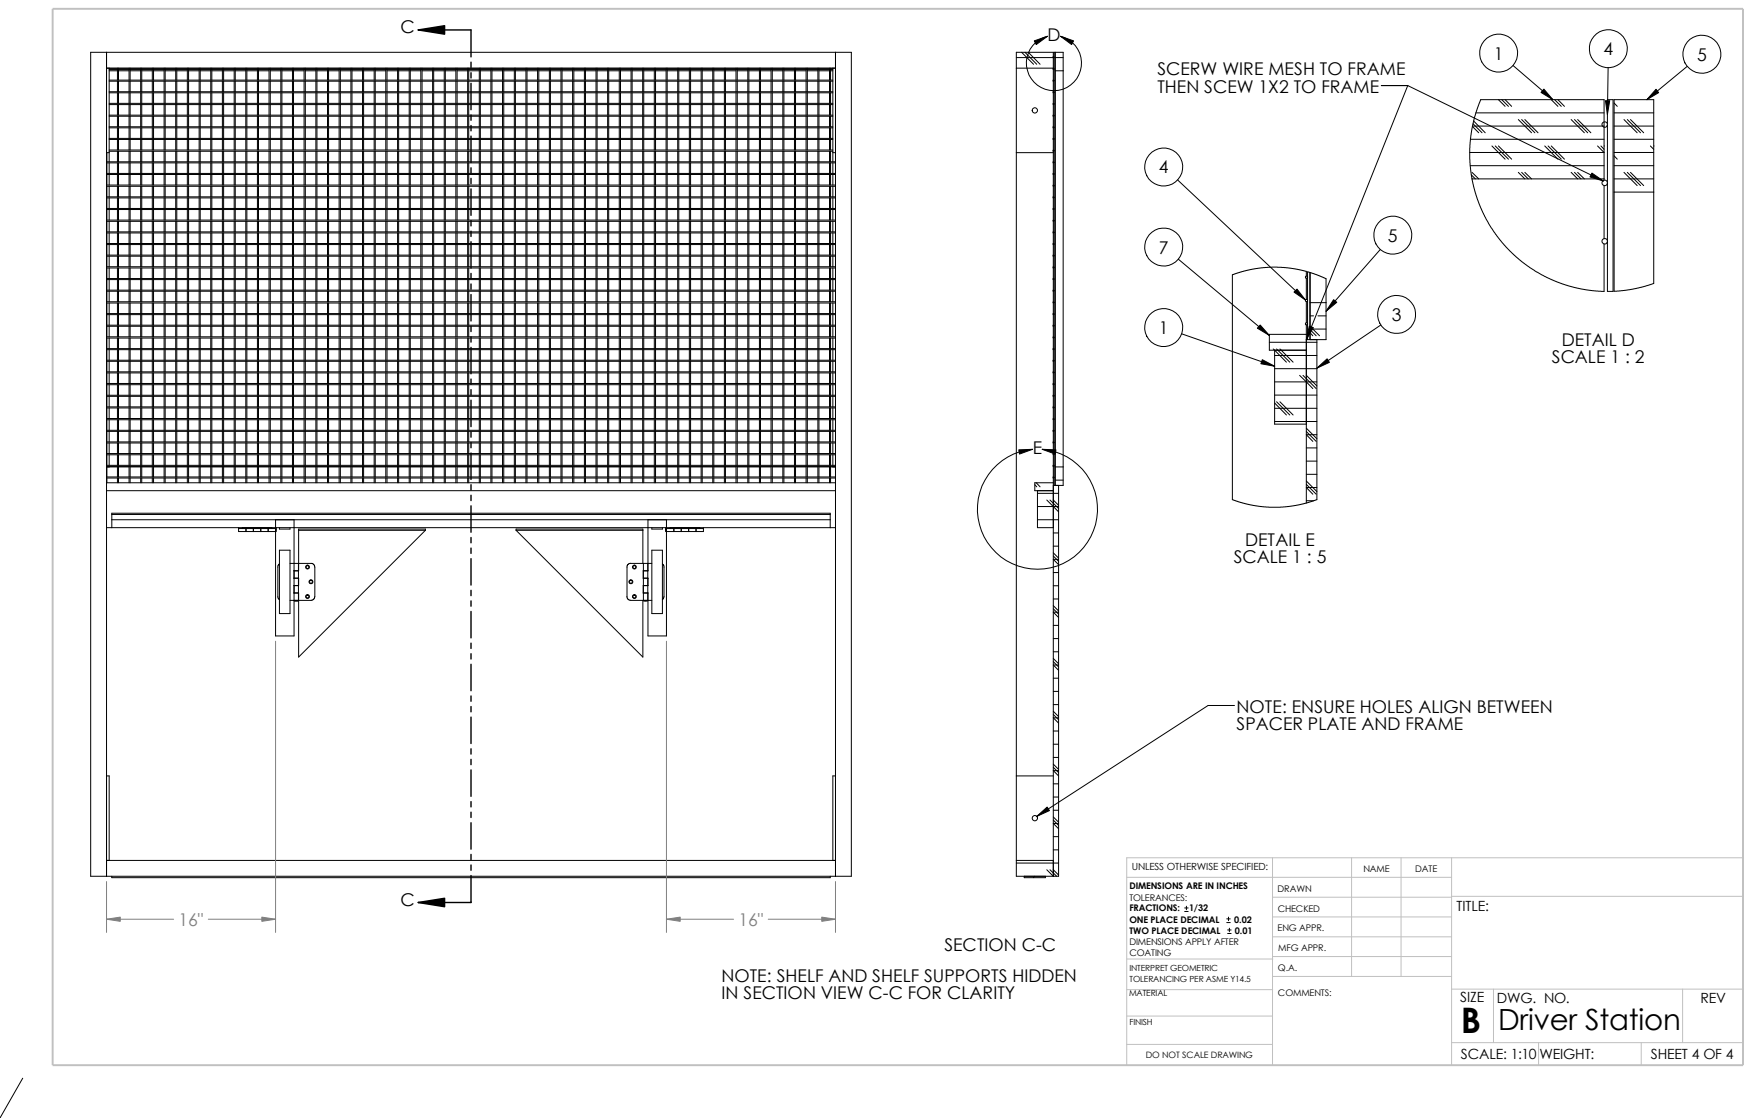
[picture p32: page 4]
Driver Station; SHEET 4 OF 4; DWG. NO.; REV; SIZE; NAME; DATE; COMMENTS:; DRAWN; MATERIAL; ONE PLACE DECIMAL; TWO PLACE DECIMAL; DETAIL D SCALE 1 : 2; SECTION C-C; DETAIL E SCALE 1 : 5

SCERW WIRE MESH TO FRAME
THEN SCEW 1X2 TO FRAME

NOTE: ENSURE HOLES ALIGN BETWEEN
SPACER PLATE AND FRAME

UNLESS OTHERWISE SPECIFIED:
DIMENSIONS ARE IN INCHES
TOLERANCES:
FRACTIONS: 1/32
DIMENSIONS APPLY AFTER
COATING

CHECKED | | TITLE:

ENG APPR.
MFG APPR.

NOTE: SHELF AND SHELF SUPPORTS HIDDEN
IN SECTION VIEW C-C FOR CLARITY

INTERPRET GEOMETRIC TOLERANCING PER ASME Y14.5 | Q.A.

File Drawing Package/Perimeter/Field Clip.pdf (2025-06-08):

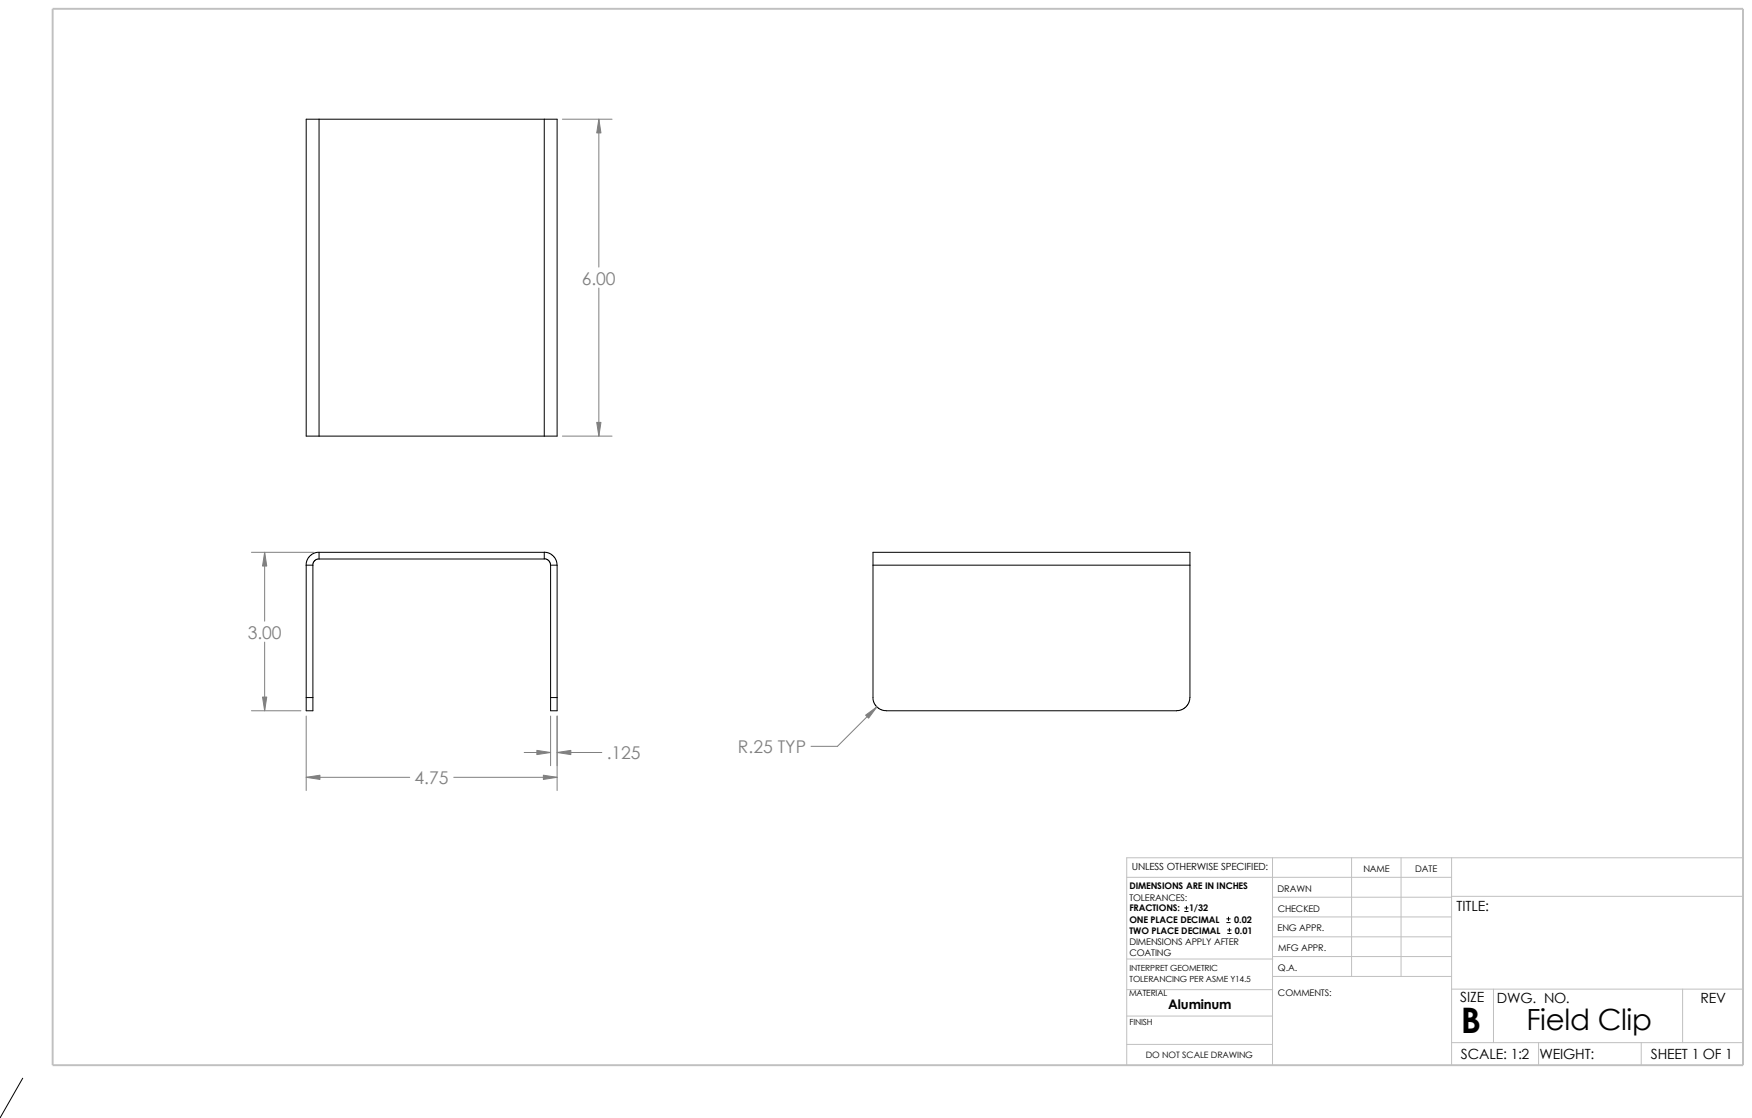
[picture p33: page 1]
SIZE; REV; COMMENTS:; Field Clip; FINISH; SHEET 1 OF 1; SCALE: 1:2; WEIGHT:; R.25 TYP

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

CHECKED | | | TITLE:

ENG APPR.
MFG APPR.

INTERPRET GEOMETRIC TOLERANCING PER ASME Y14.5 | Q.A.

MATERIAL
DWG. NO. Aluminum

DO NOT SCALE DRAWING

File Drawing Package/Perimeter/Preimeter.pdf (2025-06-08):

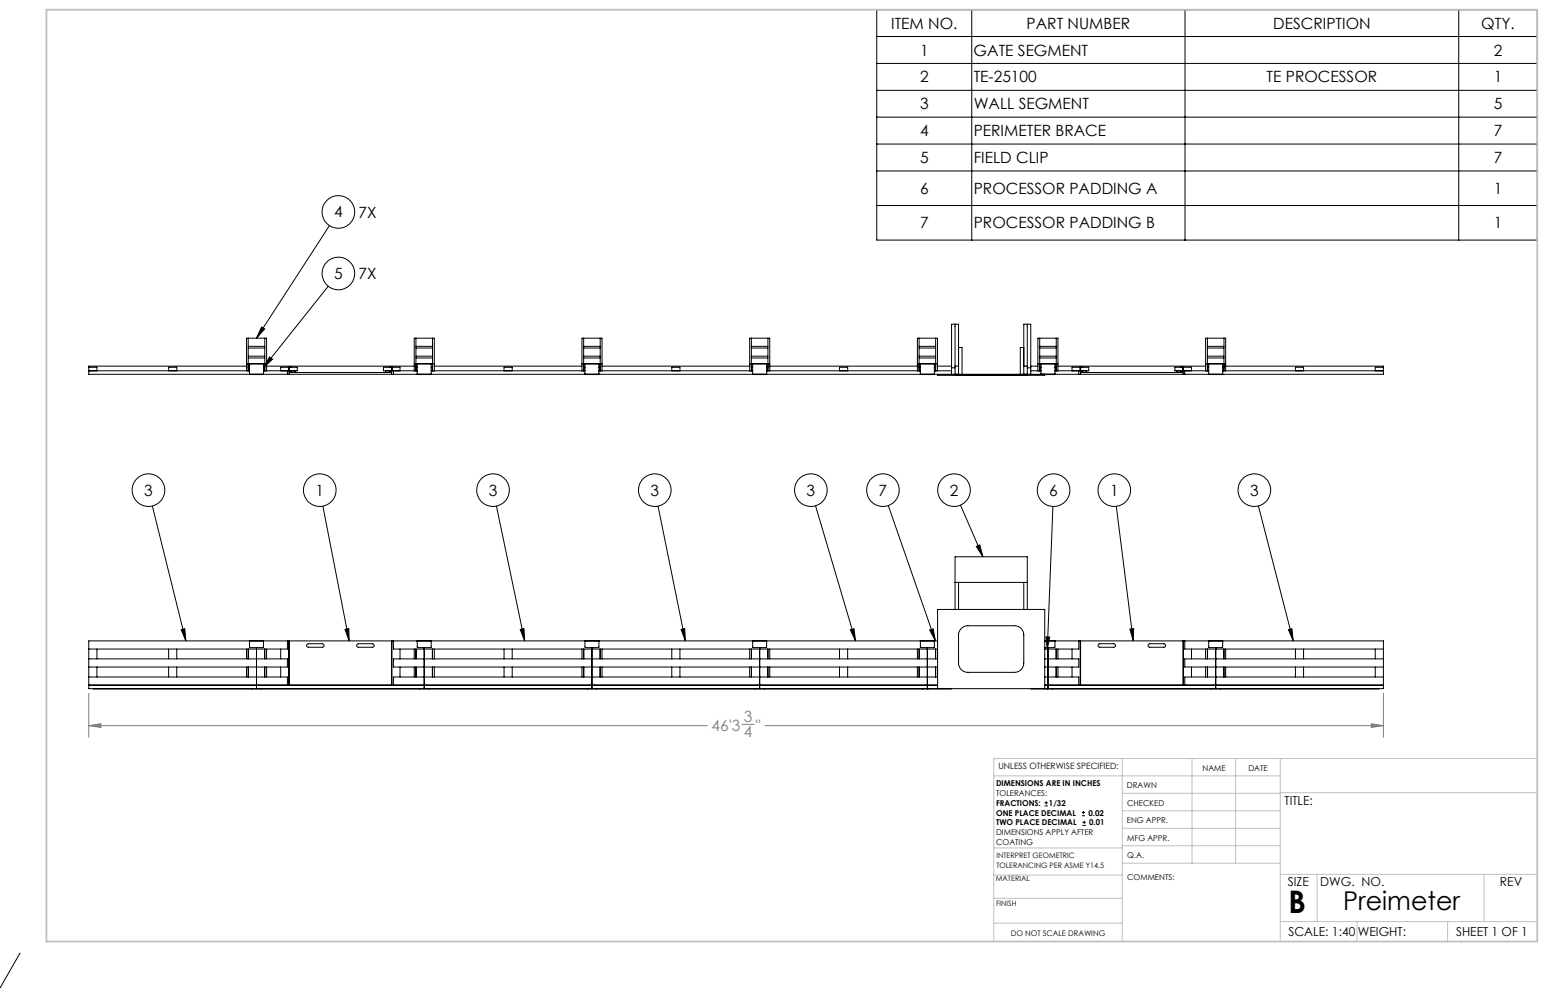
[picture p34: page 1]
ITEM NO.; PART NUMBER; DESCRIPTION; QTY.; GATE SEGMENT; TE PROCESSOR; WALL SEGMENT; PERIMETER BRACE; FIELD CLIP; PROCESSOR PADDING A; PROCESSOR PADDING B; SHEET 1 OF 1; SCALE: 1:40 WEIGHT:; DWG. NO.; REV

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

CHECKED | | | TITLE:

ENG APPR.
MFG APPR.

INTERPRET GEOMETRIC TOLERANCING PER ASME Y14.5 | Q.A.

DO NOT SCALE DRAWING

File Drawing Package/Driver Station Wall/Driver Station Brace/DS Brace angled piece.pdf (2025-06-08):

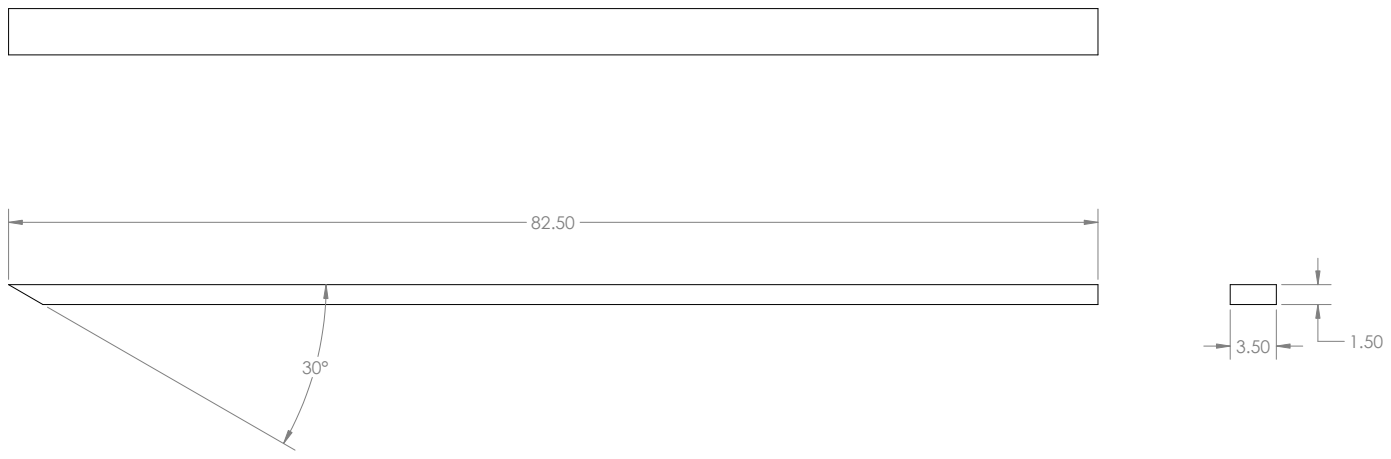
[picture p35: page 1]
SIZE; REV; COMMENTS: DWG. NO. 2x4; FINISH; MATERIAL; SHEET 1 OF 1; SCALE: 1:8; WEIGHT:

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

CHECKED | | | TITLE:

ENG APPR.
MFG APPR.

INTERPRET GEOMETRIC TOLERANCING PER ASME Y14.5 | Q.A.

2x4 DS angled piece

DO NOT SCALE DRAWING

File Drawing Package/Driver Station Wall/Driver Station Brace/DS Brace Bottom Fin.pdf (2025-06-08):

1
2

SIZE; REV; COMMENTS:; FINISH; SHEET 1 OF 1; SCALE: 1:2; WEIGHT:; " THRU ALL

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

CHECKED | | | TITLE:

ENG APPR.
MFG APPR.

INTERPRET GEOMETRIC TOLERANCING PER ASME Y14.5 | Q.A.

MATERIAL
DWG. NO. 1/2" Plywood

DS Brace Bottom Fin

DO NOT SCALE DRAWING

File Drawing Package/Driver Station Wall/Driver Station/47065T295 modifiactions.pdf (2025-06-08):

72.00

COMMENTS:; DWG. NO.; REV; SCALE: 1:8; WEIGHT:; SIZE; FINISH; 47065T295 modifiactions B; MATERIAL; SHEET 1 OF 1

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

CHECKED | | | TITLE:

ENG APPR.
MFG APPR.

INTERPRET GEOMETRIC TOLERANCING PER ASME Y14.5 | Q.A.

DO NOT SCALE DRAWING

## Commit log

2025-06-08 Perimeter Files
    [1x2.SLDPRT, 2in Hook Tape.SLDPRT, 2x4.SLDPRT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]
2025-06-08 Driver Station Wall Files
    [0.5in Loop Tape.SLDPRT, 1513A51_Mortise-Mount Hinge with Holes.SLDPRT, 1in Hook Tape.SLDPRT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]
2025-06-08 Motor City Field Top Level Files
    [Motor City Field.SLDASM, Motor City Field.SLDDRW, Preimeter.SLDASM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]
2025-06-08 2025 Drawing Package
    [Field Clip.STEP]
